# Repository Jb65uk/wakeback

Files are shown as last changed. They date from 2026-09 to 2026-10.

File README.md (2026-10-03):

# WakeBack

GPS WakeBack pucks for dinghy racing: log where you sailed, how fast and how heeled, then overlay everyone's tracks and replay the race on a projector or train against yourself.

```
wakeback/
├── viewer/index.html     the whole viewer, one file, works offline or served by the dock
├── app/                  Android phone/tablet app: the dock in your pocket, runs this same viewer (see app/README.md)
├── docs/PHONE_DOCK.md    how pucks upload to a phone hotspot instead of the dock (firmware notes)
├── server/app.py         dock server (Flask) — runs on the dock Pi, or your laptop for dev
├── tools/gen_fake_data.py    makes demo sessions in the exact puck CSV format
├── tools/fake_puck_upload.py pretends to be a puck landing on the dock
├── tools/fake_pucks.py       a dock full of pretend pucks checking in (for the Dock page)
├── data/sessions/<date>_<venue>/  one folder per session (sailing date + venue), one file per boat
├── data/venues.json      venues (Southport SC to start; new places are added as they're sailed)
├── docs/ROADMAP.md       where this is heading: your own sailing, friends, events
├── BUILD.md              build one puck on a breadboard: shopping list, wiring in stages, first track
├── hardware/carrier/     60 mm carrier PCB: Gerbers for JLCPCB, previews, assembly notes, generator
├── hardware/case/        3D-printed puck case: base, screw lid (O-ring), GPS shelf, deck cradle. STLs + generator
├── firmware/bench_test/  PlatformIO bench test: checks GPS, IMU, battery, Qi, records a test track
├── tools/pull_track.py   copies a recorded track off the puck over USB
└── firmware/             (next) the real puck firmware
```

## Quick start (VS Code)

1. Open this folder in VS Code. Install the recommended extensions when prompted.
2. `Terminal > Run Task > Install requirements` (or `pip install -r server/requirements.txt`).
3. Press F5 with **Run dock server** selected, then open http://localhost:5000.
4. The panel shows two demo sessions from the fake data: click **Sun 20 Sep, Southport SC** to load Sunday (three pucks plus Steve's phone, two races back to back in one log), press **Play**, then **B** for the big-screen projector view.
5. The course is already laid for the demo day (three marks, left to starboard). Under Races, WakeBack offers the likely races it found in the tracks: tick them and press **Add selected** (or press **Suggest races** to look again). Pick **Race 1**, then **Estimate** next to Wind. Tap **Tacks & gybes** under a boat, then filter to Tacks or Gybes, sort Worst first, and tap any one to jump the replay there.
6. `Run Task > Fake puck upload` to watch a session appear on the dock as a puck would post it.

No server? Just open `viewer/index.html` in a browser and drag files from `data/sessions/` onto it. Everything works except the sessions list and shared puck names.

## Dock page

Open **Dock** (tab at the top, or http://localhost:5000/dock). To see it with pucks in it on a laptop, run the **Fake pucks** task while the server's running: P1 full, P2/P3 charging, P4 comes back from sailing after ~20 s and uploads a session, P5 is on the pad but not charging, P6 has never checked in.

- Every puck: on the dock or away, battery % with charging / full / not charging, last upload (when, which day, how big, who sailed it), last seen, storage free, firmware (flags ones behind)
- Warnings up top: pucks not charging on the pad, low batteries
- Internet: online or not, and through what. "Connect to WiFi" scans for networks and joins one (club WiFi, a phone hotspot at an away venue). On the Pi this is real (NetworkManager, the default on Raspberry Pi OS); on a laptop it runs in demo mode with made-up networks so you can try it. The dock's own `wakeback` WiFi stays up regardless
- Dock health: disk space, clock, uptime, sessions stored, NAS backup (not set up yet)

Dock settings (environment variables):

| Variable | What | Default |
|---|---|---|
| `WAKEBACK_FLEET` | how many pucks the club has, so ones never seen still get a row | 0 |
| `WAKEBACK_WIFI` | the dock's own WiFi name, shown on the Dock page | wakeback |
| `WAKEBACK_OWNER` | owner of tracks from pucks with no owner set, e.g. `Southport SC` | none |
| `WAKEBACK_UPLINK_IF` | WiFi adapter used to reach the internet (USB dongle; onboard wlan0 runs the dock WiFi) | wlan1 |
| `WAKEBACK_PIN` | PIN needed to change the dock's WiFi | none |

## Phone / tablet app

`app/` is an Android app that runs the dock's API on the phone and shows this same viewer, so
everything above works on a phone or tablet, saved on the device, with no dock Pi:

- **No dock?** Turn on the phone's hotspot (`wakeback`): pucks join it and upload to the phone exactly as
  they would to the Pi — the dock is always the WiFi gateway on port 5000 (`docs/PHONE_DOCK.md`).
- **Sync** tab: copies each day's tracks, names, races and course both ways with this server
  (at home or on the Pi), using the API below — nothing extra on the server. **Invite a mate** sends the link.
- Build it on Windows with `app/setup.ps1` (see `app/README.md`).

The viewer knows when it's inside the app (`window.WakeBackApp`) and hands full screen and the GPX
download to the app; in a browser or on the Pi it behaves exactly as before.

## Viewer features

- Replay all boats on one clock, live speed/heel/pitch/VMG cards, 60 s trails, heading arrows
- Colour tracks by boat or by speed; satellite or OpenSeaMap chart base
- Races: split a day into time windows by hand (11:00–12:00, 12:00–13:30) or from the suggestions WakeBack works out from the tracks (boats milling about, then setting off together, then stopping; nothing is added until you tick it); stats, tacks, chart and replay all follow the selected race, and races are saved on the dock per day
- Wind direction typed in, estimated from the beating headings, or from **Get weather** (Open-Meteo: direction, speed and gusts for where and when you sailed, saved with the day, set per race, live on the map and big screen) → VMG, true wind angle, upwind/downwind averages, wind arrow on the map
- Tacks, gybes and mark roundings told apart, each with speed before/min, time back up to speed and metres lost; averages for each (tack loss, gybe loss, mark loss); click any one to jump the replay there
- Course marks: add them on the map, drag to adjust, set each to port (red) or starboard (green). Set per race, so a moved windward mark between races is fine. With marks placed, roundings are found at the real marks on any course shape (reaches included), and a rounding the wrong way is flagged
- Start and finish lines: tap the committee boat end then the pin end, drag to adjust; a line can be start, finish or both. With the gun time (typed, or estimated from the fleet) you get each boat's start: seconds late, distance back and speed at the gun, which end, and OCS (over early, and whether they went back). The finish gives order, elapsed time and gap to first. Saved per race with the marks
- Port tack red, starboard tack green: colour tracks "By tack", wind-angle chart and cards use the same colours, and the list shows which tack each manoeuvre ended on
- Wrong call? Change any tack/gybe/mark to something else, or "Not one"; corrections are saved with the session
- Align starts to race a mate from a different day or yourself from last week
- Big screen mode (B) for the projector: per-boat cards with your choice of data, loop replay, full screen (F)
- Puck numbers are fixed IDs (P3 is always P3, always the same colour); who sailed each puck is set per session, since pucks get handed out differently each time. Names you've used before pop up as suggestions
- Download all loaded tracks as one GPX to share

## Puck log format (what the firmware writes)

CSV, 10 Hz, one file per session, filename `puck<N>_<HHMMSS>.csv`:

```
t_ms,lat,lon,sog_kn,hdg,heel,pitch
1758364200000,53.6503120,-3.0101890,4.62,067,-11.3,-0.8
```

- `t_ms` UTC epoch milliseconds from the GPS
- `sog_kn` speed over ground in knots (GPS Doppler)
- `hdg` degrees true; fused IMU heading when available, otherwise course over ground
- `heel` degrees, positive to starboard
- `pitch` degrees, positive bow up

Phone/watch GPX files are accepted too; they just lack heel and pitch.

## Dock API

| Method | Path | What |
|---|---|---|
| GET | `/api/sessions` | list sessions: `[{"id":"2026-09-20_southport-sc","date","venue","venue_name","venue_new","files","count","races","owners":{"file":"name"}}]` (owners' emails are never listed) |
| GET | `/api/sessions/<session>/<file>` | fetch one track |
| POST | `/api/upload` | multipart `file` (+ optional `puck`, `owner_name`, `owner_email`, `sailor`); filed under the date of its first timestamp and the venue of its first position → `{session, file, venue, venue_name}` |
| GET / POST | `/api/venues` | list venues / add one `{"name","lat","lon","radius_m"}` (an `id` that already exists is returned as-is, for sync) |
| PUT | `/api/venues/<id>` | rename or move a venue, e.g. name an automatic "New venue near …" |
| POST | `/api/sessions/<session>/move` | `{"venue": id}`: a session filed at the wrong venue; merges into that venue's session for the day |
| DELETE | `/api/sessions/<session>/<file>` | remove a track |
| GET / PUT | `/api/sessions/<session>/races` | race windows for that day: `[{"name","start","end","gun","marks":[...],"lines":[{"kind":"start"/"finish"/"both","a":{lat,lon},"b":{lat,lon}}]}]`, times in epoch ms, a = committee boat end, b = pin |
| GET / PUT | `/api/sessions/<session>/meta` | whole-session marks, your corrections and the day's weather: `{"marks":[{"name","lat","lon","side":"port"/"stbd"}],"fixes":[...],"weather":{"src","lat","lon","got","pts":[[t_ms,dir,kn,gust],...]}}` |
| GET / PUT | `/api/sessions/<session>/crew` | who had which puck that day: `{"puck3": "Dave"}` |
| GET | `/api/sailors` | every name used in any session (for the name picker) |
| POST | `/api/pucks/checkin` | puck check-in every ~30 s on the pad: `{"puck":3,"battery_mv":4012,"charging":"charging"/"full"/"not","on_pad":true,"free_kb":12000,"total_kb":14336,"fw":"0.3.1","pending":1}`; reply carries dock time |
| GET | `/api/pucks` | every puck's status for the Dock page |
| GET | `/api/dock/status` | internet, disk, clock, uptime |
| GET / POST | `/api/wifi/scan`, `/api/wifi/connect` | find and join a WiFi network (on the Pi) |
| GET | `/api/hello` | dock time, used by pucks to confirm they're talking to the right box |

## On a NAS (or any Docker box): accounts, friends, admin

GitHub builds the server as a container on every change: `ghcr.io/jb65uk/wakeback-server:latest`.
Use `docker-compose.yml` from this repo (on a Ugreen NAS: Docker → Project → Create, paste it). It
listens on port 5090 and keeps everything in a `data` folder next to the compose file. Put it on the
internet with a Cloudflare tunnel public hostname pointing at `http://<nas-ip>:5090`. The compose file also
runs Watchtower, which checks GitHub every 30 minutes and swaps in a newer server image by itself, so the
NAS keeps up with the app without you touching it (put Cloudflare Access in front of `/admin` only, not the
whole site, or the app can't sign in), and a nightly backup container that writes `backups/wakeback-<date>.tar.gz`
(last 14 kept) — point the NAS's own backup or cloud sync at that folder so a copy leaves the building.
Password guessing is braked: 8 wrong tries on an email or 20 from one address in 10 minutes and that
login is refused for a while (a 429; the app says "Too many tries").

Set **`WAKEBACK_ADMIN`** to your email and accounts switch on:

- Everyone signs in (the app, or the viewer in a browser). New sign-ups wait for approval unless
  **Auto-approve** is on. The account with the admin email is the admin.
- **`/admin`** (admin only): approve/disable users, reset passwords, the auto-approve switch, every
  track (owner, sharing, remove), and a log of changes. Put Cloudflare Access on just this path if you like.
- Friends see each other's sails unless a sail is set **private**; tracks with no owner (a club
  dock's) are visible to all. The admin sees everything.
- Storage: `data/wakeback.db` (users, friends, tokens, log); who owns each track and its sharing
  live in the session's `owners.json`, so the phone app and a dock Pi keep the same files.

A dock Pi or the phone app runs without `WAKEBACK_ADMIN`: no logins, everything visible, as before.

## On the Pi

Same server. Set the Pi up as a WiFi access point (`wakeback`, no internet needed), run `app.py` under systemd, and point Chromium in kiosk mode at `http://localhost:5000` for the projector. Pucks join the AP when they sit on the charging pad and POST to `/api/upload`.

## Later list

Agreed, not built yet. Roughly in the order they'd make sense. The bigger direction (your own puck and phone, friends, events) is in `docs/ROADMAP.md`.

1. **Puck firmware** (ESP32-S3): 10 Hz GPS + IMU logging to the CSV format above, auto start/stop (see below), Dock check-in every ~30 s on the pad (and one as it's lifted off), upload to `/api/upload` when on the pad. The dock is found at the WiFi gateway, port 5000 — the Pi on its own WiFi, or a phone running the app on its hotspot (`docs/PHONE_DOCK.md`).
   - **Auto on/off:** asleep on the pad (never records there). Lifted → IMU wakes it → GPS fix. Records after >1.5 kn for 20 s; stops after ~10 min still, then sleeps.
   - **Travel-proof:** (a) over ~25 kn for a minute = not sailing, stop and discard; (b) needs boat-like heel/pitch rocking, not car motion; (c) only records near known venues (Southport + clubs added on the dock; dock asks "new venue?" first time somewhere new); (d) travel mode, set by triple-tap or from the dock page, sleeps until next put on a pad (use for long trips and flying).
   - Dock double-checks on upload and drops anything with road speeds or no boat motion.
   - GPS off while asleep, so a full charge lasts weeks in a bag.
2. **Home viewing, read-only**: dock syncs sessions to the home server (NAS/Tower) when online; published through a Cloudflare tunnel (e.g. puck.bridgesolutions.uk). Public copy runs the viewer locked: replay, races, colours, chart, focus a boat, tack list, big/full screen, download a track. No editing of names, races, marks or corrections; server refuses all changes. Choose per session whether it's published. Decide: club members only (Cloudflare Access email code) or anyone with the link.
3. **Up to 16 pucks**: 16 distinct colours (no red/green), compact one-row-per-boat projector view, stress test with a fake 16-boat race, bigger pad tray and power supply.
4. **Weather data**: ~~Open-Meteo~~ done — **Get weather** fills in wind direction, speed and gusts per race (hourly model). Next: the SSC weather station when it's running (log direction/speed every few seconds with a timestamp) for real shifts, lifts and headers — same `meta.weather.pts` format, just finer.
5. **Offline map backgrounds**: dock keeps the satellite/chart tiles for each venue it's been online at, so away venues work without internet.
6. **Leg analysis**: with marks placed, split each race into legs and show who gained or lost on each beat and run.
7. **NAS backup** of sessions from the dock.

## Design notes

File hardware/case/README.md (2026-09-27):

# WakeBack puck case

A round puck, 86 mm across and 37 mm tall, made to fit the carrier board and the parts on the shopping list. It has four printed parts (plus two optional ones for hanging it under a thwart, below):

| File | What it is | Print it |
|---|---|---|
| `out/wakeback-base.stl` | The cup. The battery, Qi coil, carrier board and TP4056 go inside. Bayonet lugs round the bottom | As it comes, floor down |
| `out/wakeback-lid.stl` | Screw-on lid with a thread and an O-ring seal | Top face down (the file is already that way up) |
| `out/wakeback-bridge.stl` | GPS shelf. Sits over the heel sensor on two legs | Flat side down (already that way up) |
| `out/wakeback-cradle.stl` | Deck mount. Drop the puck in and twist it clockwise to lock it | As it comes |

Plus two optional parts for hanging the puck **under a thwart** instead of on the deck:

| File | What it is | Print it |
|---|---|---|
| `out/wakeback-lid-mount.stl` | The same lid, with three bayonet lugs round its rim | Top face down (already that way up) |
| `out/wakeback-cradle-lid.stl` | A wider cradle that fits that lid. Screws to the underside of the thwart; the puck twists in upside down | As it comes |

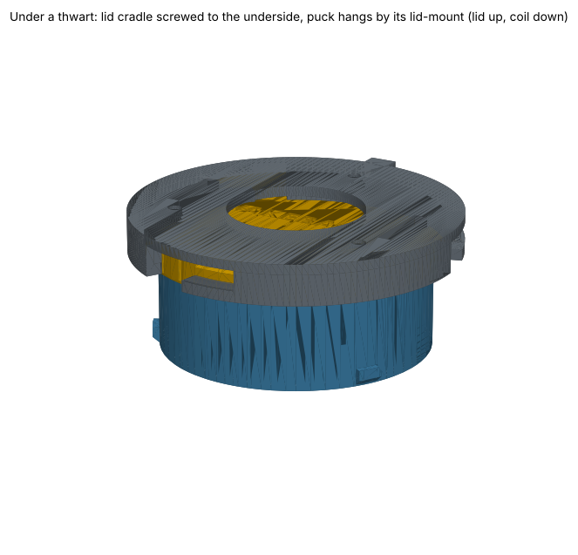
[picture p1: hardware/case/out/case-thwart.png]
under the thwart


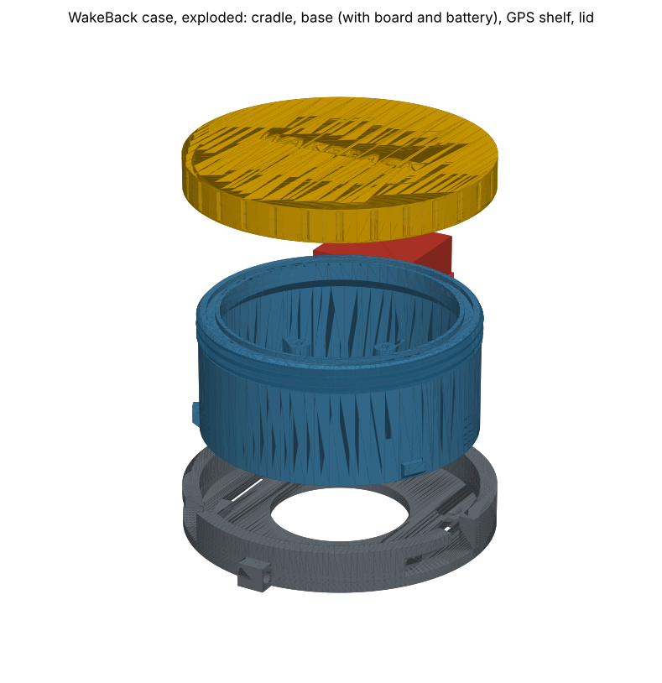
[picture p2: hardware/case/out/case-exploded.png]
exploded

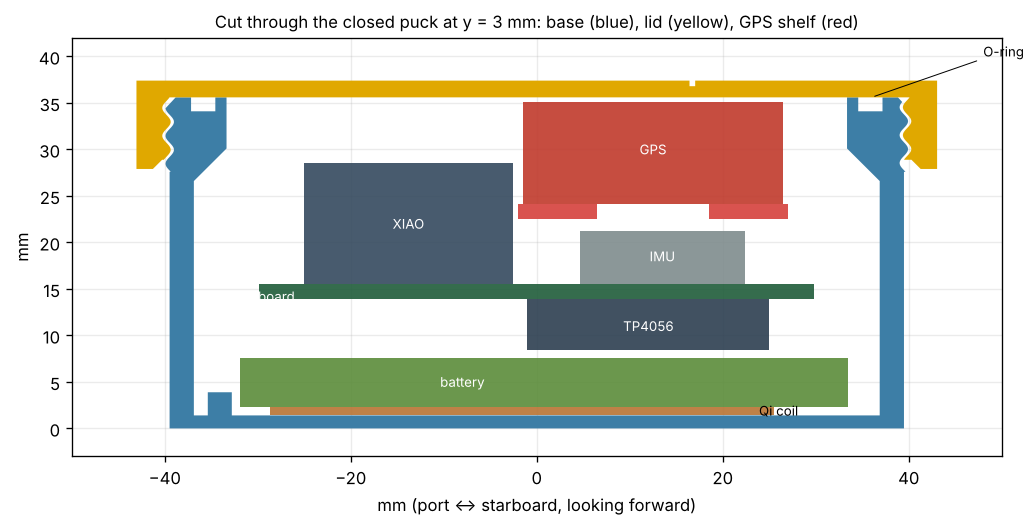
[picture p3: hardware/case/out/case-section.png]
section


## Print settings

- **PETG** (easy, tough) or **ASA** (better in sun for years). Not PLA: it softens in a hot boat and creeps.
- 0.2 mm layers, **5 perimeters**, 6 top and 6 bottom layers, 40 % gyroid infill. No supports needed.
- Flow at 100–103 %. Slight over-extrusion helps it stay watertight.
- Check the lid screws on before you print the cradle. If the thread is tight, raise `THREAD_CLR` in `gen_case.py` by 0.1 and re-run it.

## Also buy

- O-ring **70 × 2 mm**, nitrile. A pack of 10 is a couple of pounds.
- M2.5 stainless screws: **2 × 20 mm** (board and GPS shelf) and **1 × 8 mm** (third board hole). Self-tapping, or plain machine screws; either cuts its own thread in the plastic.
- A 1 mm self-adhesive foam pad for the top of the GPS, and double-sided foam tape.
- A little silicone grease for the O-ring.
- For the cradle: 3 × No.6 (3.5 mm) countersunk stainless screws, or a 20 mm Velcro strap through the two slots.

## Putting it together

1. **O-ring:** grease it lightly and press it into the groove on the rim of the base.
2. **Qi coil:** stick it to the middle of the floor, coil side down (touching the floor), shield sticker side up. The thinner the gap to the pad, the better it charges.
3. **Qi receiver board:** stick it down in the gap beside the battery, on the starboard-aft side (see `case-plans.png`).
4. **Battery:** it drops in between the four corner stops, sitting on the coil. It goes in at an angle so it misses the three board posts. Tilt it to get it past the rim.
5. **Carrier board:** onto the three posts, heel-sensor arrow toward the arrow on the outside of the base. One **M2.5 × 8** screw goes in the hole by the XIAO.
6. **GPS:** stick it on the shelf with foam tape, ceramic antenna facing up. Put the shelf over the heel sensor and fix it with the two **M2.5 × 20** screws, through the shelf legs and the board into the posts. Add the 1 mm foam pad on top of the GPS.
7. **Lid:** screw it on hand-tight. It's a normal thread: clockwise closes, anticlockwise opens.

The inside heights are tight. The battery top sits 6.3 mm under the board, and the TP4056 needs 5.5 mm, so keep the wires under the board flat.

## Check it's watertight

Before any electronics go in: put a dry tissue inside, screw the lid on, and hold it under water in a sink for 30 minutes (weigh it down). The tissue should come out dry. If it's damp, look for the leak: usually a thin wall or a gap between layers. Print again with 6 perimeters, or brush the outside with a thin coat of epoxy (XTC-3D or similar).

It floats. It displaces about 196 cm³ and weighs about 130 g with everything in.

## The cradle

- Screw or strap it to the boat with its **arrow pointing at the bow**.
- Hold the puck with its side arrow about 20° anticlockwise of the cradle arrow. Push it down, then twist it clockwise until the arrows line up. It clamps down as it goes home.
- Tie a thin lanyard through the eye on the cradle to the puck, in case of a big capsize.
- To charge it, twist it out and lay it on the Qi pad, flat side down.

## Under the thwart (lid-mount)

- Print the lid-mount and the lid cradle; the base, shelf and O-ring are the same. Swap lids as you like: both screw onto the same base.
- Screw (3 × No.6) or strap the lid cradle to the underside of the thwart, **arrow to the bow**. Screws go up into the wood; the heads sit inside the cradle.
- Screw the lid-mount onto the puck so the small arrow on its top face lines up with the base's bow arrow as near as you can (it doesn't need to be exact, see below).
- Offer the puck up lid-first, arrow about 20° anticlockwise of the cradle's arrow (as you look up at it), push, twist clockwise until the arrows meet. It hangs lid-up, charging coil down.
- Tie the lanyard through the cradle's eye. Upside down, the lugs are what's holding it; the lanyard is the belt to those braces.
- GPS: the antenna now faces up into the thwart. A wooden or GRP thwart is fine (plywood, a foam-cored GRP thwart, a Solo's mahogany one); a **carbon** thwart or a metal plate will block it — go on deck instead. Expect a slightly slower first fix and the odd extra metre of scatter.
- Heel and pitch: the puck is upside down and turned to whatever angle the lid tightened at. The firmware detects "upside down" from gravity at rest and learns the twist from the difference between its compass heading and the GPS course when you're sailing straight — nothing to set. Until that's in, the phone app's puck setup will have a "mounted: deck / under thwart" choice.
- The lid-mount also works on deck in the normal cradle (its lugs clear the deck cradle), so one puck can carry the lid-mount all the time and go either way.

## Things to know

- The status LED is inside. If you want to see it, print the lid in clear or natural PETG.
- **GPS power:** Beitian lists the BE-880 at 3.6–5.5 V, and the board feeds it 3.3 V. Most of these modules run happily on 3.3 V, and Stage 2 of the bench test will show you. If it won't get a fix or keeps dropping out, move the GPS red wire from the 3V3 pad to OUT+ on the TP4056 (battery voltage).
- Everything is generated by `gen_case.py`: sizes at the top, then the parts. Run it again after any change. It checks that nothing inside hits the case, that the lid unscrews cleanly, and that the puck drops into the cradle and twists to lock. Then it rewrites the STLs and pictures. It needs `pip install manifold3d trimesh numpy matplotlib`.

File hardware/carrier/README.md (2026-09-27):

# WakeBack carrier board v1

A 60 mm round, 2-layer board that replaces the breadboard. The same modules from the shopping list in `BUILD.md` solder onto it; there's nothing new to buy apart from the resistors and LED in 1206 size.

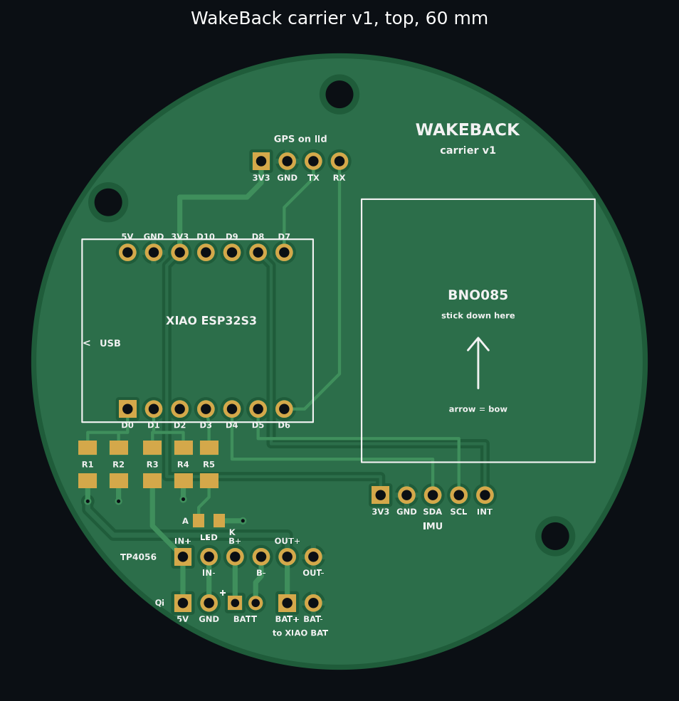
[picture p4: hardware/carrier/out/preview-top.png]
top


## Ordering from JLCPCB

1. Go to jlcpcb.com, **Order now**, upload `out/wakeback-carrier-v1-gerbers.zip`.
2. Settings: 2 layers, 1.6 mm, any colour, HASL lead-free finish. Leave everything else at default. It should read 60 × 60 mm.
3. "Remove order number": pick **Yes** or **Specify a location**, otherwise JLCPCB prints their number somewhere on the silkscreen.
4. Shipping: pick the economy option, not DHL.
5. Optional but recommended: turn on **PCB Assembly** (Economic, top side) and upload `out/wakeback-carrier-v1-BOM.csv` and `out/wakeback-carrier-v1-CPL.csv`. JLCPCB then fits R1–R5 and the LED (all their "basic" parts, about £8–10 extra). In the placement preview, check the LED's cathode mark sits on the K pad.

## What goes where

**Top side**
- **XIAO ESP32S3** on its header pins, USB-C facing the board edge (marked). Tip: use two 7-pin female headers so the XIAO can come off again.
- **R1 to R4: 100 kΩ, R5: 300 or 330 Ω**, all 1206. **LED** 0805: the A pad goes toward R5, and the green mark on the LED (cathode) toward K. (Skip if JLCPCB fitted them.)
- **BNO085**: stick it inside its outline with foam tape, arrow pointing to the bow. Five short wires from its pins to the IMU pads: 3V3 → VIN, GND, SDA, SCL, INT.
- **GPS pads**: four wires up to the BE-880 on the lid (3V3, GND, TX, RX, labelled from the GPS's point of view: its TX goes to the TX pad).

**Bottom side** (the pads are labelled on both sides)
- **TP4056** module inside its outline, USB end to the edge. Six short wires: IN+, IN−, B+, B−, OUT+, OUT−.
- **Qi receiver**: 5V and GND to the Qi pads. The board itself sits next to the battery, and the coil goes under the battery against the case base.
- **Battery**: JST-PH socket; the square pad is **+**. **Check the battery's polarity with a meter first.**
- **XIAO BAT pads**: two thin wires from the BAT+ and BAT− pads on the XIAO's underside to the BAT+/BAT− pads. Solder these to the XIAO *before* fitting it.

## Check it before powering up

With a meter on continuity, nothing connected yet:
- GND to 3V3: **not** connected
- OUT+ (VSYS) to GND: **not** connected
- IN− (Qi GND) to GND: **not** connected. They're deliberately separate, because the TP4056 protection circuit sits between them.

Then fit the modules one at a time in the same order as the breadboard stages in `BUILD.md`, running the bench test after each.

## Design notes

- Pins match `firmware/bench_test`: D0 battery sense, D1 pad sense, D3 LED, D4/D5 I2C, D6/D7 GPS, D8 IMU interrupt.
- Bottom layer is a ground fill. Clearances are 0.25 mm minimum (JLCPCB allows 0.127), copper is 0.5 mm from the edge, and labels are 0.8 mm tall or more.
- Three M2.5 mounting holes.
- The board is generated by `gen_carrier.py`. Change it and run it again: it checks clearances and that every connection is joined, then rewrites the Gerbers and the previews.

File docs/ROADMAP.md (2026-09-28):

# WakeBack roadmap: sailing's version of a running app

Everyone records their own sailing, looks back at it, and shares it with friends or an event.
The club base station (dock + projector) is one more way of recording, for training days with lots of people.

```
own puck ─► own phone (the app is a pocket dock) ─┐
                                                   ├─► WakeBack server (app.py, at home behind Cloudflare)
club pucks ─► dock Pi at the club ─────────────────┘        accounts · friends · events · venues
```

## Decisions (27 Sep 2026)

- **Accounts:** invite-only for now (you add people); can open up later without a rebuild.
- **Sign-in:** email + password (no email service needed); the admin resets passwords from /admin. The app stays signed in.
- **Privacy:** a new sail is visible to **friends** by default; any one can be made private or public.
- **Clean-up:** the QR phone-upload page is gone (mates use the app instead); old Bluetooth design dropped.

## Words

- **Session:** a sailing date + venue (`2026-09-20_southport-sc`). Everything replayed together.
- **Track:** one boat's log in a session. Has an **owner** (whose puck/phone sent it: can edit/delete it)
  and a **sailor** (who was in the boat; pucks get lent, so this is set per session).
- **Venue:** where you sailed. Found from the first position; somewhere new gets "New venue near …" until named.
- **Event** (stage 3): a set of tracks replayed together across owners: "Solo open, West Kirby", "Tuesday training".

## Stages

1. **Venues + owner/sailor** ✅ (this change)
   Sessions by date + venue; venue detection, naming, "wrong venue?" move; owner recorded on every track
   (phone profile, puck's owner, or the club); your old date-only folders are converted automatically;
   the app has a "You" profile; sync keeps venues and owners.
2. **Accounts and sharing** ✅
   Email + password accounts on the server (SQLite), approval or auto-approve, admin dashboard at /admin,
   friends, friends/private per track, only the owner (or admin) edits or deletes, the app signs in and
   keeps demo data separate. Not yet: a public read-only link, email "forgot password".
2b. **Sessions tab, stats and the league** ✅
   The app opens on a native Sessions list (tap to replay, Friends/Private switch per session), with Stats
   (miles, hours, sessions, average, top speed, fastest average, longest sail, favourite venue, miles by
   month, a fun comparison) and a friends' League (miles, hours, top speed, best average; this month / year /
   all time; medals). Numbers come from `server/stats.py` (`/api/stats`, `/api/league`, `stats` in
   `/api/sessions`, cached per session in `stats.json`) and the identical Dart port `app/lib/dock/stats.dart`
   for what's on the phone. Private sails stay off everyone's board, including the admin's.
3. **Events and "who else was there?"**
   Create an event, share a link/code, everyone adds their track; the server spots other WakeBack sailors at
   the same venue and time and offers to ask them; a feed of your and your friends' sailing.
4. **Puck setup from the app** (with the firmware) — TO DO, first once a puck is on the bench
   On first power-up (or holding the button) the puck puts up its own WiFi `wakeback-puck-N` for a couple of
   minutes; the app joins it and sends hotspot name + password, the owner, and a **puck key** (random,
   issued by the server, tied to the owner's account — club pucks to the club account). The puck sends the
   key with every upload; nobody types or remembers it. Lost/sold puck → revoke the key in /admin and set it
   up again. Lost hotspot password → change it on the phone and re-tell the puck the same way.
4b. **Firmware: calibrate itself, don't make the sailor do it** — TO DO (with the firmware)
   - Which way up: gravity at rest → deck cradle or hanging under the thwart; flip heel/pitch signs to suit.
   - Mounting twist: compass heading (BNO085) minus GPS course while sailing straight, averaged → the angle the
     puck is turned from the bow; re-learnt each time it's locked in, so the lid can stop at any angle.
   - Level: the "flat" heel/pitch offset from the first minutes at rest on the trolley/pontoon (and the cradle
     not being quite level on deck).
   - Magnetometer: run the BNO085's own calibration in the background; save it so it survives a power cycle.
   - GPS: nothing to calibrate, but do warm-start (save last fix + almanac) so it's ready when the boat hits the water.
   - Report all of it (orientation, twist, level, mag status) in the check-in so the app can show "puck 3 is
     under the thwart, calibrated" or warn when it isn't.
5. **Firmware from the dashboard → app → puck** — TO DO
   /admin: upload a `.bin` + version + notes; server serves `/api/firmware/latest`. The app shows
   "Puck 3 is on 1.2, 1.4 available — Update" on the Dock page and pushes it while the puck is on the pad /
   the hotspot (ESP32 OTA). Rule: keep the previous image and roll back if the new one doesn't check in
   within a minute — one bad build must not brick the club's pucks on a Saturday.
6. **App update button** ✅ (28 Sep)
   Every build is signed with the permanent key (GitHub secrets) and its build number is the run number, so
   the release tag `app-N` and the installed build match. The app checks the public releases feed (every 6 h,
   or Setup → About → Check), shows an "Update available" card with the release notes (the commit message)
   on Sessions and in Setup, downloads the APK and hands it to Android's installer (`app/lib/updates.dart`).
   One-off: phones with a throwaway-key build must uninstall once.
7. **2FA (TOTP) on accounts** — TO DO
   Authenticator-app codes, no SMS/email service; optional for sailors, on for the admin; admin can turn it
   off for someone who's lost their phone (from /admin, like a password reset).

8. **GDPR / keeping personal data tight** — TO DO
   The server holds names, emails, password hashes and GPS tracks (which are personal data too: where
   someone was, when). To do: a short privacy note in the app and on the server (what's kept, why, who sees
   it); emails never leave the server (already: the API only sends names) and never appear in the viewer,
   logs or the audit trail beyond what the admin needs; **delete my account** in the app and /admin that
   removes the account *and* their tracks (or hands club tracks to the club); **export my data** (a zip of
   your tracks + account details); a friend can only see your email if you've accepted them; keep the
   Cloudflare-fronted server HTTPS-only, back-ups encrypted, and the SQLite/data folder off any shared NAS
   share. No third-party analytics or trackers, so nothing to consent to beyond the account itself.

9. **Make it fun / useful — picked 27 Sep, in this order** ✅ (28 Sep; all five, phone side; server computes the same stats)
   1. **Personal bests**: when a session lands, a toast + card — "Fastest average this year", "Longest sail
      ever", "New top speed". Stats already has the numbers; keep a small `bests.json` per person.
   2. **Offline maps**: cache map tiles for your venues (a few zoom levels round each) so the tablet works
      with no signal at the club; "Download this venue" in Setup.
   3. **Share card**: a PNG of the track on the map + date/venue/miles/top speed/average, straight to WhatsApp
      via the Android share sheet.
   4. **Streaks & badges**: sailed N weekends running, 100 nm month, first 6 kn, dawn sail, most miles at a
      new venue, first capsize (heel > 80° for 10 s — the IMU knows). All from data already logged.
   5. **Wind vs speed**: upwind / downwind averages and bests, best 30-s VMG, most heel and capsizes (heel > 80°
      for 10 s), and a table by wind strength — from the day's weather (meta.weather, so pull it in on Replay)
      and the puck's heading and heel. `server/stats.py` and `app/lib/dock/stats.dart` compute it identically.
   Also: `app/lib/dock/badges.dart` (bests + 17 badges), `app/lib/dock/tiles.dart` (tile cache served at
   `/tiles/<layer>/z/x/y` by the phone's dock; the in-app viewer uses it), `app/lib/share_card.dart`.

Done 28 Sep, security: login/sign-up rate limits (accounts.py), Watchtower auto-updates the server image,
nightly backups to ./backups on the NAS (still to do: a copy off the NAS — the NAS's own backup app to the
PC or cloud). Still open: the update button needs the repo public (or a separate public releases repo).

Also still on you: add the GitHub signing secrets; scope Cloudflare Access to `/admin` only so the app can
create accounts.

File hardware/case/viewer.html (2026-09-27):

# WakeBack case

Round puck, 86 mm across and 37 mm tall. Screw-on lid with an O-ring, GPS on a shelf under the lid, twist-lock cradle for the deck. Drag to turn it, pinch or scroll to zoom.

Loading the model…

The small arrow on the side of the base points to the bow

TogetherApart

Cut in half Parts inside Lid Cradle

## Colours

## Print these

Part | Size, mm | Weight
Base | 80 × 82 × 36 | ~44 g
Lid, top face down | 86 × 86 × 10 | ~21 g
GPS shelf, flat side down | 30 × 49 × 9 | ~2 g
Cradle | 90 × 94 × 12 | ~30 g

Material

PETG or ASA

Layer

0.2 mm

Walls

5 perimeters

Top/bottom

6 layers

Infill

40 % gyroid

Supports

none

## Also buy

- O-ring 70 × 2 mm, nitrile
- 2 × M2.5 × 20 mm stainless screws (board and GPS shelf)
- 1 × M2.5 × 8 mm stainless screw (third board hole)
- 1 mm foam pad for the top of the GPS
- 3 × No.6 countersunk stainless screws for the cradle, or a strap
- A little silicone grease for the O-ring

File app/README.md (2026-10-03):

# WakeBack app (Android phone / tablet)

**The dock in your pocket.** The app runs the same API as `server/app.py` on the phone and shows the
**real viewer** (`viewer/index.html`) — races, marks, start/finish lines, tacks & gybes, wind, big screen,
crew names, venues, weather, the Dock page — all saved on the phone. Every session is a date + venue, and everything
your phone records is marked as yours (the You tab).

- **No dock Pi yet?** Turn on the phone's hotspot. Pucks join it and upload to the phone exactly as they
  would to the Pi (same `/api/pucks/checkin` and `/api/upload`).
- **Your server** (`app.py` at home or on the Pi): the **Sync** tab copies each day's tracks, names,
  races and course both ways. **Invite a mate** sends the server link.
- Works at the lake with no signal (Leaflet is bundled; only the map background needs internet).

```
app/
  lib/dock/store.dart         the dock's storage + rules, ported line for line from server/app.py
  lib/dock/pocket_dock.dart   the dock's HTTP API on port 5000 + serves the viewer pages
  lib/dock/stats.dart         miles / hours / speeds / wind / heel per track, totals and the league (= server/stats.py)
  lib/dock/badges.dart        personal bests ("new record") and badges, from your tracks
  lib/dock/tiles.dart         map tile cache: the dock serves /tiles/... so Replay works offline
  lib/share_card.dart         the picture of a session for WhatsApp
  lib/updates.dart            checks GitHub releases, downloads + installs a newer build
  lib/sync/server_sync.dart   two-way sync with your server (existing endpoints only)
  lib/demo/                   fake_pucks.py + gen_fake_data.py, ported
  lib/screens/                three tabs: Sails (list, Stats, League), Record, You. Replay (the viewer) opens when you tap a sail; Sync is behind the cloud on Sails
  assets/web/                 viewer pages (copied from ..\viewer by setup.ps1) + Leaflet
  test/dock_test.dart         checks the phone dock answers like app.py (incl. stats), and sync between two docks
  test/fixtures/              two small tracks whose numbers were taken from server/stats.py
```

## 1. Install Flutter (once, ~15 min)

1. Download the Flutter SDK zip for Windows (docs.flutter.dev → Get started → Windows → Android),
   extract to `C:\dev\flutter`, add `C:\dev\flutter\bin` to your user PATH, open a new terminal.
2. Install **Android Studio**, open it once to finish setup, then:
   ```
   flutter doctor --android-licenses
   flutter doctor
   ```
   Ticks for *Flutter* and *Android toolchain* are what matter.

## 2. Set up and test

```powershell
cd <wakeback folder>\app
.\setup.ps1
.\setup.ps1 -Test        # "All tests passed!"
```

## 3. Run it

- **Emulator on the PC:** Android Studio → Virtual Device Manager → + → Pixel 8 → newest image → ▶. Then `.\setup.ps1 -Run`.
- **Your phone (USB):** Developer options → USB debugging on, plug in, `.\setup.ps1 -Run`.
- **Mate's phone:** `.\setup.ps1 -Build` → send `WakeBack.apk`.

Press `r` in the terminal to reload after a change, `q` to quit.

## 4. Try it

1. **You → Advanced → Try the demo → Add a demo race morning.** Back on **Sails**, tap the day to replay it; in Replay open the panel (on a phone: the
   panel button) → today's date → it's the full viewer: suggested races, Race 1, Estimate wind, tacks & gybes,
   start results, **Big screen**, **Full screen**.
2. **You → Demo pucks** on, then **Advanced → See your pucks**: five pucks charging; P4 comes back after
   ~20 s and uploads a session that appears in the list.
3. **Sync:** run your server on the PC (`python server\app.py`), then in the emulator use
   `http://10.0.2.2:5000` (the emulator's name for your PC) → **Check** → **Sync**. Open
   `http://localhost:5000` on the PC: the demo day's there with its races and course.
   On a real phone use the PC's LAN address, e.g. `http://192.168.1.20:5000`.

## Pucks uploading to the phone (no dock)

1. Android Settings → Hotspot: name **wakeback** (or whatever you set in You → Advanced) and the password your
   pucks use. Turn it on.
2. Open WakeBack and keep it open (screen on is safest) while pucks sit on their charging pads.
3. Pucks join, check in every ~30 s and upload. Watch them on the viewer's **Dock** tab.

The firmware side is in `docs/PHONE_DOCK.md`: pucks look for the dock at their WiFi **gateway** on
port 5000, which is the Pi on its own WiFi and the phone on its hotspot — one code path for both.

## Troubleshooting

| Problem | Fix |
|---|---|
| `flutter` not recognised | PATH not set, or terminal opened before you set it |
| Build asks for a different NDK version | copy the `ndkVersion = "…"` line it prints into `android\app\build.gradle.kts` under `android {` |
| You → Advanced shows "Couldn't open port 5000" | another app has it; restart the phone. Replays still work, pucks can't upload until then |
| Sync: "Can't reach the server" | check the address (include `http://` or `https://`); from the emulator the PC is `10.0.2.2` |
| Map background blank | no internet for tiles — tracks, marks and lines still draw |

Anything else — paste the error.

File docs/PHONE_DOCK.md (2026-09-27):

# Phone as the dock — what the puck firmware needs

No new protocol. A phone running the WakeBack app answers every dock URL the same way
`server/app.py` does, on port **5000**. So the firmware has one upload path, and only
needs to know *where* the dock is:

**The dock is the WiFi gateway, port 5000.**

| Where | Puck joins | Gateway = | Dock URL |
|---|---|---|---|
| Club, dock Pi | the Pi's own AP `wakeback` | the Pi | `http://<gateway>:5000` |
| No dock | the phone's hotspot `wakeback` | the phone | `http://<gateway>:5000` |

Firmware flow when on the pad (unchanged, just the address lookup):

1. Join SSID `wakeback` (password in NVS).
2. `GET http://<gateway>:5000/api/hello` → `{"dock":"wakeback","time_ms":…}` confirms it's a dock
   (and sets the clock if there's no GPS time yet). No reply → try again later.
3. `POST /api/pucks/checkin` every ~30 s (and once as it's lifted off the pad).
4. `POST /api/upload` (multipart `file`, plus `puck=puckN`) for each finished session;
   delete from flash only after a `200` with `{"ok":true}`.

On the ESP32: `WiFi.gatewayIP()` after connecting.

Things that differ with a phone, and the app handles:

- The phone only accepts uploads while WakeBack is open (Android may pause it in the
  background). Pucks just retry on their next check-in.
- `/api/dock/status` reports `can_manage_wifi: false` and `phone: true`; the Dock page hides
  "Connect to WiFi" and says to use the phone's hotspot.
- Android hotspots often use `192.168.43.1` or `10.x.x.1`, never assume the address — use the gateway.

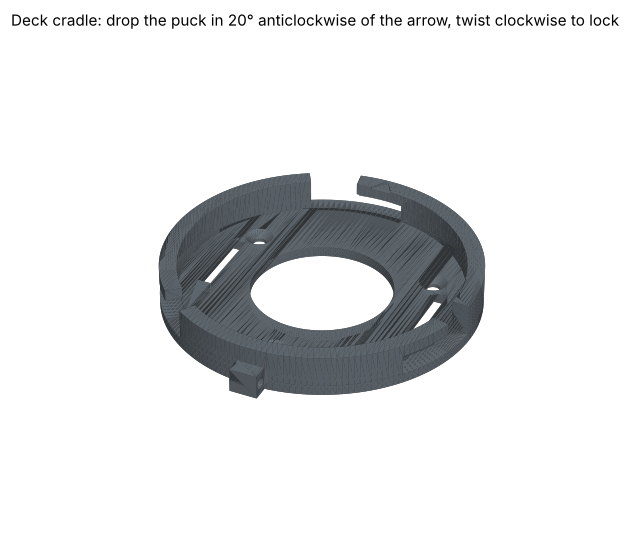
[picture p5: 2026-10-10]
hardware/case/out/case-cradle.png

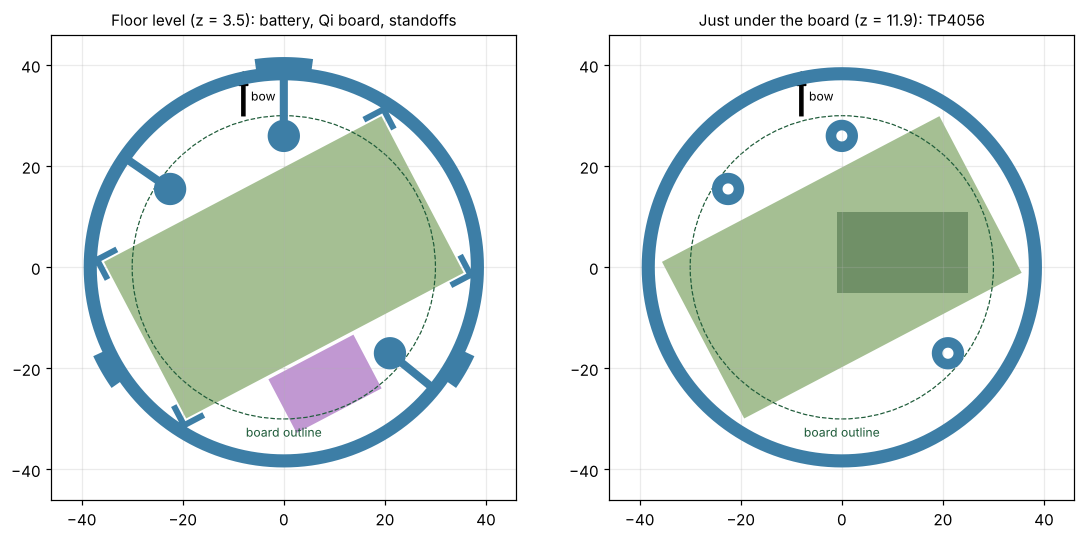
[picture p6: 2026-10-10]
hardware/case/out/case-plans.png

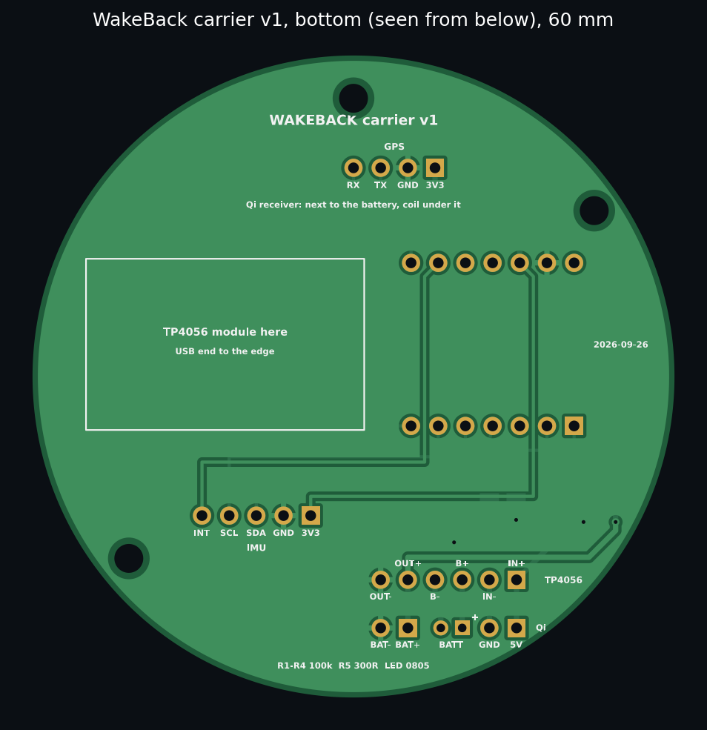
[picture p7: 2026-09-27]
hardware/carrier/out/preview-bottom.png

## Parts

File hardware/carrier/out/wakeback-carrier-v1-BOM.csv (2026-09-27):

Comment | Designator | Footprint | JLCPCB Part #
100k | R1,R2,R3,R4 | R_1206 | C17900
300R | R5 | R_1206 | C17887
LED red | D1 | LED_0805 | C84256

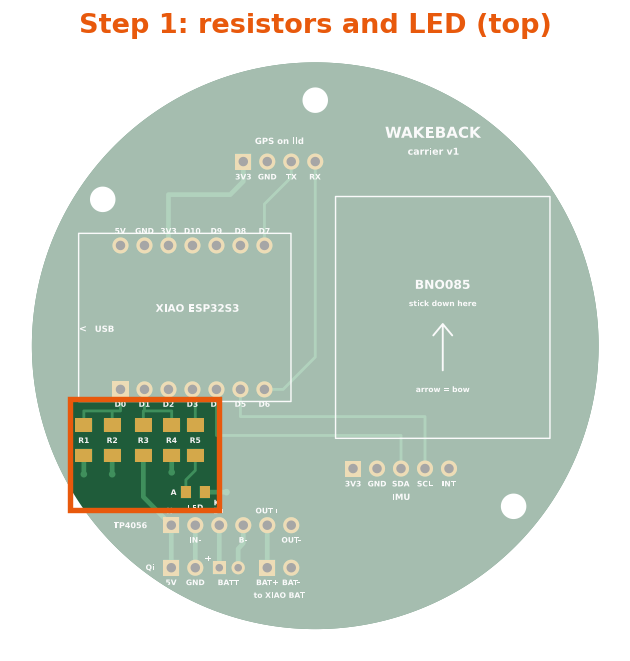
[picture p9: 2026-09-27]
hardware/carrier/out/step-parts.png

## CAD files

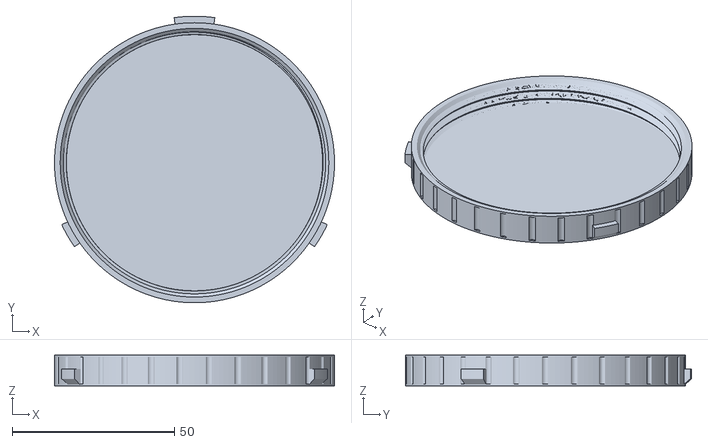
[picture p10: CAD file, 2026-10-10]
hardware/case/out/wakeback-lid-mount.stl
86.3 x 88.3 x 9.50

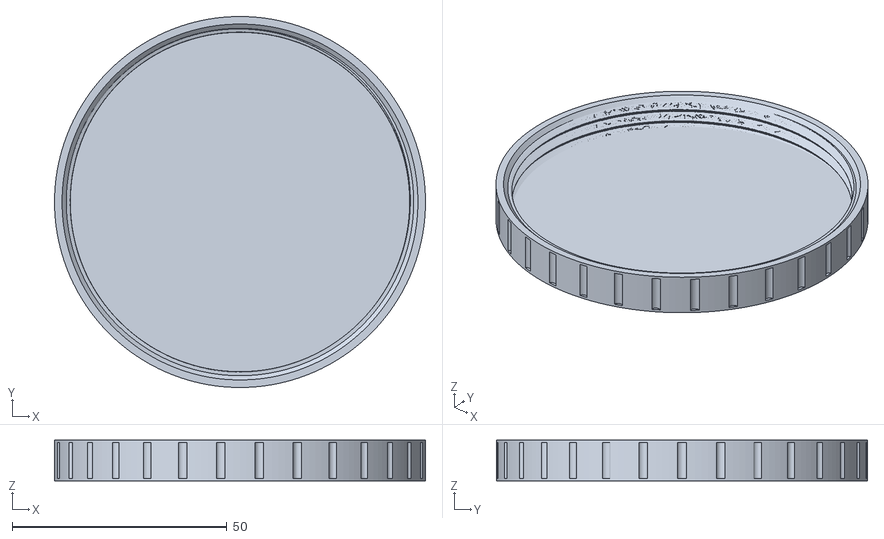
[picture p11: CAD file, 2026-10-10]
hardware/case/out/wakeback-lid.stl
86.3 x 86.3 x 9.50

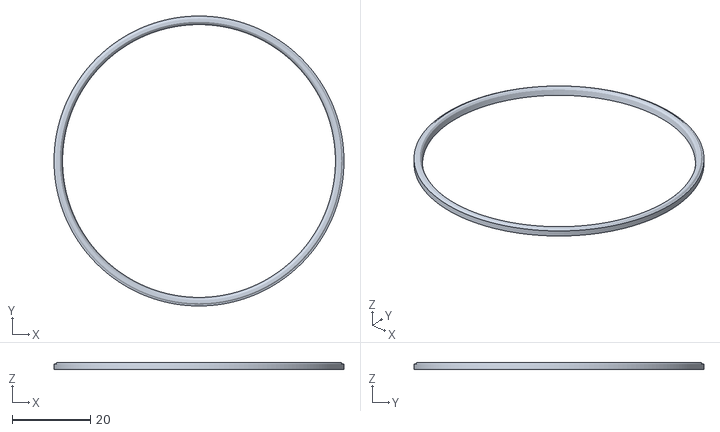
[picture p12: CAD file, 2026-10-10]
hardware/case/out/wakeback-gasket-tpu.stl
74.2 x 74.2 x 1.90

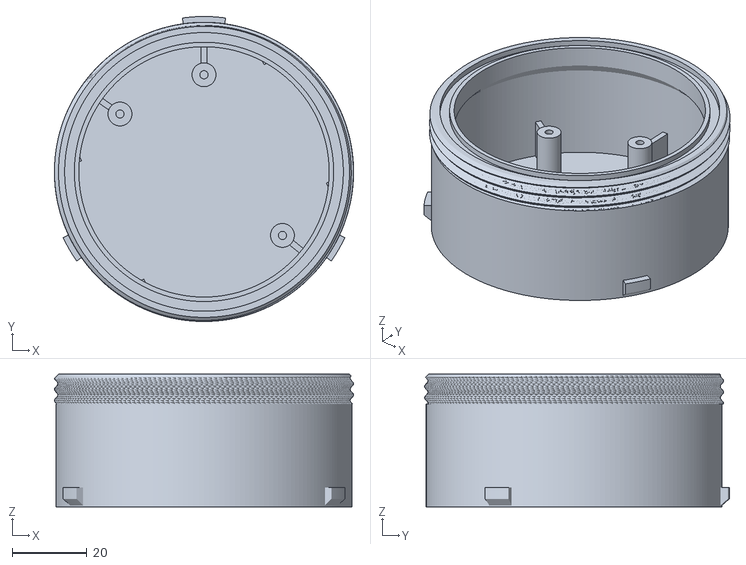
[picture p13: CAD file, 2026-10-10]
hardware/case/out/wakeback-base.stl
80.1 x 81.6 x 35.6

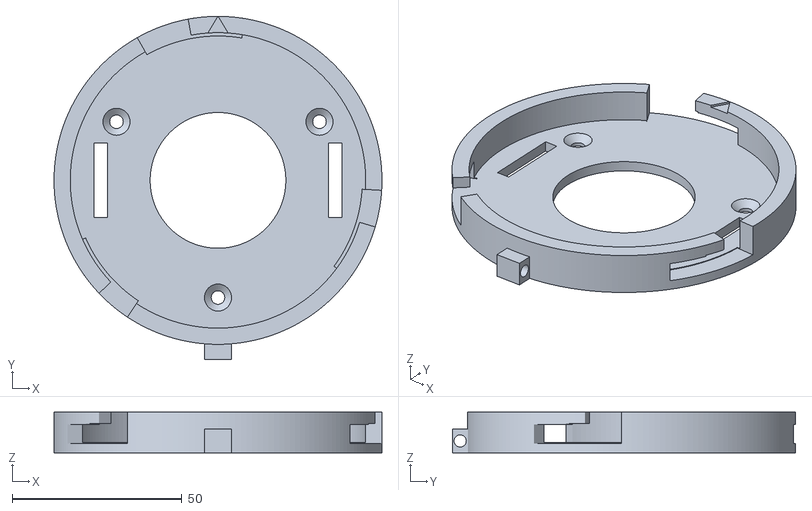
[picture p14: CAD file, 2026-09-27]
hardware/case/out/wakeback-cradle-lid.stl
96.7 x 101.2 x 12.0

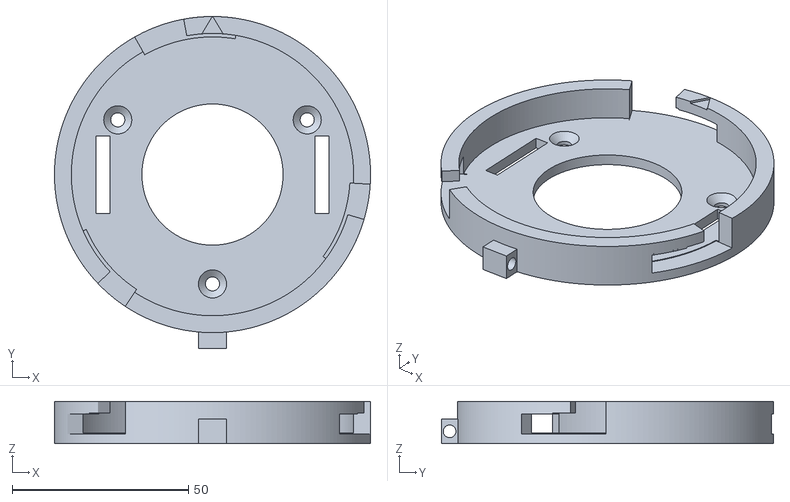
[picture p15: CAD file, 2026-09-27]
hardware/case/out/wakeback-cradle.stl
89.6 x 94.1 x 12.0

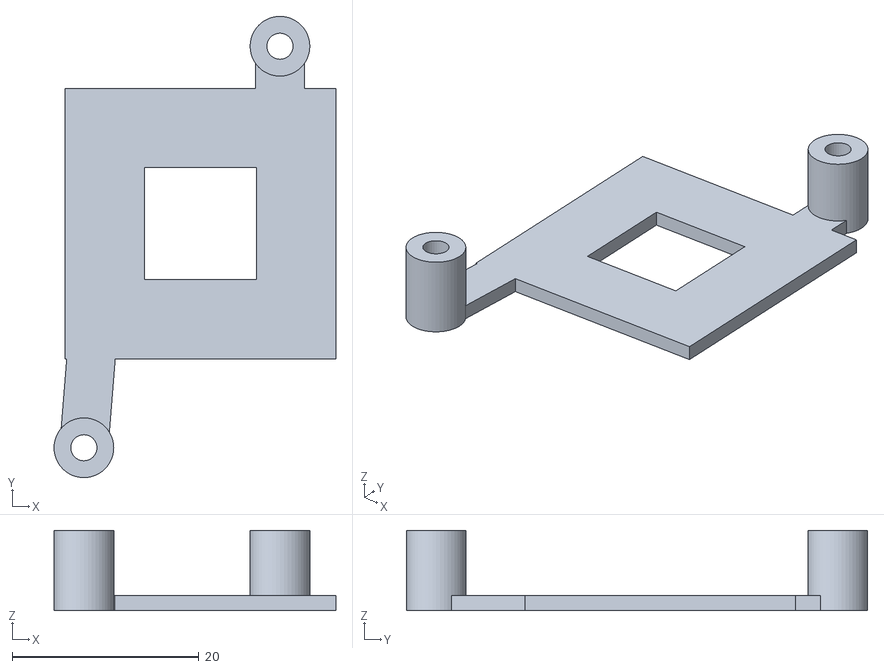
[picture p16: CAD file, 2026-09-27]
hardware/case/out/wakeback-bridge.stl
30.2 x 49.4 x 8.60

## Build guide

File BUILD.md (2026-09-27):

# Build one puck on a breadboard

Goal: one working puck on the bench, then a first real track off the water, before any PCB or case.
Build it in stages and check each one before adding the next. If something doesn't work, you'll know which part it is.

**Two ways to build it:** on a breadboard (below), or on the **carrier board**: a 60 mm round PCB the same modules solder onto, about £5 for five from JLCPCB. See `hardware/carrier/README.md`. The stages and checks below are the same either way.

## Shopping list

Prices checked 26 Sept 2026, including VAT. Stock moves, so check before ordering.

| Part | Where | Price | Notes |
|---|---|---|---|
| Seeed XIAO ESP32S3, **pre-soldered headers** | [The Pi Hut](https://thepihut.com/products/seeed-studio-xiao-esp32s3) | £8.20 | For the breadboard. The PCB later uses the Plus (16 MB); this one has 8 MB, plenty for testing |
| Adafruit BNO085 9-DOF IMU (heel/pitch) | [SB Components](https://shop.sb-components.co.uk/products/adafruit-9-dof-orientation-imu-fusion-breakout-bno085-bno080-stemma-qt-qwiic) (in stock) or [The Pi Hut](https://thepihut.com/products/adafruit-9-dof-orientation-imu-fusion-breakout-bno085-bno080-stemma-qt-qwiic) (sold out today) | £27 | Comes with header pins to solder on |
| Beitian **BE-880** GPS (u-blox M10) | Amazon UK / AliExpress, search "BE-880 GPS M10" | about £15–20 | Make sure it says **BE-880** or M10. The older **BN-880** (M8) works but isn't as good. Ignore its compass wires |
| LiPo 1200 mAh, JST-PH, with protection | [The Pi Hut](https://thepihut.com/products/1200mah-3-7v-lipo-battery) | £8 | 62 × 35 × 5 mm. Any 1000–1200 mAh single-cell with protection will do |
| TP4056 charger boards **with protection** (DW01), USB-C, pack of 5+ | Amazon UK, search "TP4056 USB-C protection" | about £6 | The ones with 6 pads: IN+ IN− B+ B− OUT+ OUT− |
| Qi receiver, 5 V 1 A, with coil | [Amazon UK (VBESTLIFE)](https://www.amazon.co.uk/Vbestlife-Wireless-Charging-Receiver-Standard-default/dp/B08H8LL341) | about £5–8 | Any "Qi receiver module 5V 1A" |
| Qi charging pad | any phone pad | about £10 | Or one you already have |
| Breadboard, jumper wires, 4 × 100 kΩ, 1 × 330 Ω, 1 LED | any starter kit | about £10 | Skip what you already have |
| JST-PH 2-pin sockets / pigtails | Amazon UK | about £5 | So the battery plugs in rather than being soldered |

For the **carrier board** instead of a breadboard, add: a JST-PH 2-pin through-hole socket (B2B-PH-K-S), and two 7-pin 2.54 mm female headers for the XIAO. The resistors and LED can be fitted by JLCPCB when you order (about £8–10 extra); to solder them yourself, add 100 kΩ ×4 and 300–330 Ω ×1 in **1206** size and an **0805** LED.

About **£85–95** with the pad and breadboard, **about £70** for the puck parts alone.

Tools: soldering iron (IMU headers, two wires on the XIAO's battery pads, TP4056 wires), multimeter (to check battery polarity).

### Before you start: LiPo safety
- **Check the battery polarity with a multimeter before plugging it in anywhere.** Cheap LiPos swap red and black on the JST plug more often than you'd think. Reversed = dead charger, possibly a hot battery.
- Never short the battery leads, and never leave a LiPo charging unattended on a bench.
- For now, don't leave it on the Qi pad **and** plugged into USB at the same time (two chargers on one cell). A minute for testing is fine.
- The TP4056 boards charge at 1 A out of the box. That's quicker than this battery likes (it recommends about 0.6 A). For bench tests it's OK; before real use, swap the small resistor marked R3 (or R-prog) for **2.2 kΩ** (about 550 mA).

## Software

1. Install the **PlatformIO** extension in VS Code.
2. Open the folder `firmware/bench_test` (just that folder) in VS Code.
3. Plug the XIAO in with a USB-C data cable. Click **Upload** (→ on the blue bar). First time takes a few minutes while it downloads the tools.
4. Click the **Serial Monitor** (plug icon). Type `h` and Enter for the commands.

Every second it prints a status line like:

```
GPS 3D fix, 14 sats, 10 Hz, +/-1.8 m | 3.21 kn 045 deg | heel +12.3 pitch  -1.0 | batt 3.98 V 78% | off the pad
```

## Stage 1: the XIAO on its own

Push the XIAO into the breadboard across the middle gap, USB end at the edge. Upload the bench test.

**Check:** the monitor says `GPS: NOT FOUND` and `IMU: NOT FOUND` (nothing's connected yet) and the LED blinks slowly. Storage says ok with about 6 MB free.

## Stage 2: GPS

| BE-880 wire | goes to XIAO |
|---|---|
| VCC (red) | 3V3 |
| GND (black) | GND |
| TX (from the GPS) | **D7** |
| RX (to the GPS) | **D6** |
| SDA / SCL (compass) | leave unconnected |

Wire colours vary between sellers: go by the labels on the board. TX goes to the XIAO's receive pin (D7), and RX to D6. Crossed is correct.

Press the XIAO's reset button (or re-open the monitor). Put the GPS on a window sill or outside, antenna (the square ceramic side) facing the sky.

**Check:** `GPS: found at 38400 baud, set to 10 Hz`. Within a minute or two outside: `3D fix`, 10+ sats, `10 Hz`, accuracy under 3 m. Indoors it may never get a fix; that's normal.

If it says NOT FOUND: swap D6/D7, check 3V3 and GND.

## Stage 3: heel and pitch (BNO085)

Solder the header pins onto the BNO085 first.

| BNO085 pin | goes to XIAO |
|---|---|
| VIN | 3V3 |
| GND | GND |
| SDA | **D4** |
| SCL | **D5** |

Reset. **Check:** `IMU: found`. Put the breadboard flat and type `z` (zero). Heel and pitch read about 0.

Now decide which way the puck will sit on the boat, and tip the board the way the boat heels **to starboard**: heel should go **positive**.
- If tipping sideways changes *pitch* instead: type `a` (swap axes), sit it level, `z` again.
- If heel goes negative: type `f` (flip).

These settings are remembered.

## Stage 4: status LED

D3 → 330 Ω → LED long leg; LED short leg → GND.

**Check:** slow blink with no GPS fix, one blink a second with a fix, double blink when recording.

## Stage 5: battery and charger

**Unplug the USB first.**

1. **Check the battery polarity** with the multimeter.
2. Battery → TP4056 **B+ / B−**.
3. TP4056 **OUT+ / OUT−** → the XIAO's **BAT+ / BAT−** pads underneath (solder two short wires). Nothing goes to the XIAO's 5V pin.
4. Battery sense: TP4056 OUT+ → 100 kΩ → **A0** (D0) → 100 kΩ → GND.

Unplug USB: the XIAO should run from the battery (LED blinking). Plug USB back in to see the monitor.

**Check:** `batt 3.9x V nn%`. The reading should be within about 0.05 V of the multimeter across the battery.

## Stage 6: wireless charging

1. Qi receiver 5 V out → TP4056 **IN+ / IN−** (the pads beside its USB socket).
2. Pad sense: Qi 5 V → 100 kΩ → **A1** (D1) → 100 kΩ → GND.
3. Lay the Qi coil flat on the pad.

**Check:** the TP4056 red LED lights (charging), the monitor says `on the pad, charging`. Lift the coil: `off the pad`. When full the TP4056 LED goes blue/green and the monitor says `full`.

If the pad doesn't start: centre the coil, and try another pad. Some are fussy with small coils.

## Stage 7: first real track

1. In the monitor type `p1` (this is puck 1), then `r` to start recording.
2. Unplug USB, put the breadboard in a food box, and go for a walk, a bike ride, or better, a sail. It records whenever it has a fix.
3. Back home: plug in, **close the serial monitor**, then in a terminal in the project folder:

```
pip install pyserial
python tools/pull_track.py
```

It saves `puck1_HHMMSS.csv`. Drop it on the viewer (or add `--upload` with the dock server running and it lands in the right session).

About 3 hours fits on the 8 MB XIAO (about 1.9 MB an hour as text). The real firmware stores it more compactly.

## What's not on the breadboard (yet)

- The AO3401 GPS power switch (only matters for sleeping for weeks).
- Wake-on-movement, auto start/stop, dock check-ins and uploads. That's the real firmware, next.

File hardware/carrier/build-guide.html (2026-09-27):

# WakeBack build guide

Building the first puck on the carrier board, from ordering the PCB to a real track on the viewer. No electronics knowledge needed beyond being able to solder. Do the steps in order: each one ends with a test, so if something's wrong you know exactly which bit.

This is the first build. The board and the test firmware have been checked on the computer but not yet built for real. Treat puck one as the prototype, and expect to find a thing or two to change.

## What you're building

One round board with everything wired to it. The small computer (XIAO) and the heel sensor sit on top. The charger module sits underneath, the battery below that, and the wireless charging coil under the battery. The GPS goes in the lid, facing the sky, on four wires.

{{STACK}}

Top of the carrier board: XIAO outline on the left, heel sensor outline on the right, pads labelled for GPS, IMU, charger, Qi and battery

The board, top side. 60 mm across.

Bottom of the carrier board, seen from underneath: outline where the charger module sits and the same pads labelled

Underneath, as you'll see it when you turn it over.

### How it's all connected

{{OVERVIEW}}

powergrounddatacharging

## Order the boards

Done

Shipping: DHL is about £30. Pick the cheapest economy option at checkout instead (usually called Global Standard Direct Line or similar): a few pounds, and about 2 weeks.

Yes, you just send it. The file wakeback-carrier-v1-gerbers.zip is everything a PCB factory needs. Don't unzip it: upload the zip as it is.

1. Go to jlcpcb.com and make an account.
2. Click Order now, then Add gerber file, and pick the zip.
3. After a few seconds it shows a picture of the board and fills in the size: it should say 60 × 60 mm and 2 layers. Click the preview to check it looks like the pictures above.
4. Check the settings below. Most are already right.
5. Save to cart, then Checkout. Pick a shipping option: the cheapest takes a couple of weeks, DHL/FedEx about a week.

Setting | Choose | Why
Base material | FR-4 | standard
Layers | 2 | filled in from the files
PCB qty | 5 | the minimum, and the same price as fewer
PCB thickness | 1.6 mm | standard
PCB colour | Green | cheapest and quickest; any colour works
Surface finish | HASL (with lead) or LeadFree HASL | either is fine to hand-solder
Outer copper weight | 1 oz | standard
Remove order number | Yes (small extra charge) | otherwise they print a code somewhere on the board. Harmless, so No is fine too
PCB Assembly | On (recommended) | JLCPCB fits the five resistors and the LED for you. See below
SMT stencil | Not needed

### Let JLCPCB fit the resistors and LED (recommended)

The tiny parts are the fiddliest bit to hand-solder, and they're all JLCPCB "basic" parts, so it's cheap to have them fitted. Everything else (XIAO, modules, battery socket, wires) you still solder yourself.

1. On the same order page, switch PCB Assembly on. Choose Economic, Top Side, PCBA Qty 2 (the other 3 boards come bare). Tooling holes: Added by JLCPCB. Click Confirm.
2. Upload wakeback-carrier-v1-BOM.csv as the BOM and wakeback-carrier-v1-CPL.csv as the CPL (pick-and-place) file, then Process BOM & CPL.
3. It should find three parts, all ticked: C17900 (100 kΩ ×4), C17887 (300 Ω) and C84256 (red LED). If one says out of stock, pick any other 1206 resistor of the same value, or any 0805 LED, from the basic list.
4. On the placement preview, zoom in on the LED. Its cathode mark (the little line or dot) should sit on the pad labelled K, toward the right. If it's the wrong way round, select it and rotate it 180°. Resistors don't matter.
5. Carry on to the cart. Expect roughly £8–10 extra for assembly (a setup fee plus pennies for the parts).

Expect about £5 for the boards plus shipping. UK VAT is normally added at checkout on small orders, so there's nothing extra to pay on delivery. It'll ask you to confirm the order after their engineers check the files, usually within a few hours.

## Parts and tools

Got everything

Part | How many | Notes
Carrier board (from JLCPCB) | 1 (of 5)
Seeed XIAO ESP32S3, pre-soldered headers | 1 | The Pi Hut (https://thepihut.com/products/seeed-studio-xiao-esp32s3), £8.20
Beitian BE-880 GPS (u-blox M10) | 1 | Amazon / AliExpress, about £15–20. Must say BE-880 or M10
Adafruit BNO085 heel sensor | 1 | SB Components (https://shop.sb-components.co.uk/products/adafruit-9-dof-orientation-imu-fusion-breakout-bno085-bno080-stemma-qt-qwiic), £27
TP4056 USB-C charger with protection (6 pads) | 1 | Amazon pack of 5, about £6
Qi receiver 5 V 1 A, with coil | 1 | Amazon (https://www.amazon.co.uk/Vbestlife-Wireless-Charging-Receiver-Standard-default/dp/B08H8LL341), about £5–8
LiPo 1200 mAh, JST-PH plug, protected | 1 | The Pi Hut (https://thepihut.com/products/1200mah-3-7v-lipo-battery), £8
The next three are only needed if you didn't have JLCPCB fit them:
Resistor 100 kΩ, 1206 size | 4 | R1 to R4. Marked "104" on the part
Resistor 300 or 330 Ω, 1206 size | 1 | R5. Marked "301" or "331"
LED, 0805 size, any colour | 1
JST-PH 2-pin socket, through-hole (B2B-PH-K-S) | 1 | for the battery to plug into
Female header, 1 × 7, 2.54 mm | 2 | so the XIAO can come off again
Thin silicone wire, 26–28 AWG, several colours | 1 m | red, black, and two or three others
Qi charging pad | 1 | any phone pad

### Tools

- Soldering iron with a fine tip (330–350 °C), solder, and a flux pen
- Fine tweezers, for the tiny resistors
- Multimeter: for checking the battery's + and −, and for the continuity checks
- Foam double-sided tape, and a USB-C data cable

## Soldering tips

### The tiny parts (resistors and LED)

They look fiddly but they're the easiest thing on the board once you know the trick:

1. Put a small blob of solder on one of the two pads.
2. Hold the part with tweezers, heat that blob, and slide the part into it. Take the iron away and it's held.
3. Solder the other end normally.
4. Go back and touch the first end again with a dab of fresh solder so it flows properly.

### Wires

- Strip about 2 mm, twist, and tin the end (coat it with solder) before it goes near the board.
- Push the wire through the pad's hole from the side the module is on, and solder on the other side. Snip the spare.
- Keep wires short and neat: just long enough to reach, plus a little slack.

LiPo battery safety. Before you plug the battery into anything, check its + and − with the multimeter. Cheap batteries often have the red and black swapped in the plug, and a backwards battery can destroy the charger or make the battery swell. Never short the leads, and never leave it charging unattended on the bench.

## Set up the computer

Done

You'll use this to put the test program on the XIAO and to see what it reports.

1. Install VS Code from code.visualstudio.com.
2. In VS Code, click the Extensions icon on the left (four squares), search PlatformIO IDE, and install it. It takes a few minutes and may ask to restart.
3. Unzip wakeback.zip somewhere, then File → Open Folder… and pick wakeback/firmware/bench_test (that folder, not the whole project).
4. Wait until the blue bar at the bottom shows a ✓ tick and a → arrow. That means it's ready.

You'll use three buttons on that blue bar:

- ✓ Build makes sure the program compiles.
- → Upload puts it on the XIAO.
- Plug icon: Serial Monitor shows what the XIAO is saying. Type commands at the bottom and press Enter.

Check: click ✓ Build now, before any hardware arrives. The first time it downloads its tools (several minutes). It should end with SUCCESS. If it shows an error instead, send it to me: the test program hasn't been built on a real machine yet, and a small fix may be needed.

1

## Resistors and LED

Done

Had JLCPCB fit these? Just check the LED is there and the right way round, tick Done and skip to Step 2.

Soldering them yourself? You need: the board, 4 × 100 kΩ, 1 × 300 or 330 Ω, a 0805 LED.

Board with the five resistor positions and LED position highlighted, bottom left of the XIAO outline

Label on board | Part | Marked
R1 R2 R3 R4 | 100 kΩ | 104
R5 | 300 or 330 Ω | 301 or 331
LED | LED, see below

Resistors can go either way round. The LED can't.

{{LED}}

Check: each part sits flat with both ends shiny and joined. Nothing bridges across to its neighbour.

2

## XIAO

Done

You need: the XIAO, two 7-pin female headers, a short red and a short black wire (about 60 mm each).

Board with the XIAO position highlighted; the USB end is marked at the left edge

1. First, the battery wires. Turn the XIAO over. Near one end there are two small pads labelled BAT+ and BAT− (look for the + and −). Solder the red wire to BAT+ and the black to BAT−. Do this now, because once the XIAO is fitted you can't reach them.
2. Push the two female headers into the board's 14 XIAO holes from the top. Solder one pin of each underneath, check they're straight, then do the rest.
3. Plug the XIAO into the headers with its USB socket at the board edge, matching the "USB <" marking.
4. Leave the two battery wires loose for now. They go on in step 6.

Orientation matters. If the XIAO goes in the wrong way round, nothing will work and the power pins will be in the wrong place. The USB socket must point at the board edge.

3

## First power-up

Done

1. Plug the XIAO into the computer with the USB-C cable.
2. In VS Code click → Upload. Wait for SUCCESS.
3. Click the plug icon to open the Serial Monitor. Press the XIAO's tiny R (reset) button to see it start.

WakeBack bench test starting…
GPS:     NOT FOUND. Check VCC/GND, and that GPS TX goes to D7 and GPS RX to D6.
IMU:     NOT FOUND. Check VIN/GND, SDA to D4, SCL to D5.
Storage: ok, 5.9 MB free

Check: you see something like the above. GPS and IMU not found is right: they aren't fitted yet. The LED on the board blinks slowly.

Upload fails? Unplug the USB, hold the XIAO's B (boot) button, plug back in, let go, and upload again. You only need to do this the first time.

4

## GPS

Done

You need: the BE-880 GPS and its wires. It'll live in the lid, so give the wires enough length to reach (about 80 mm) and cut the rest off.

Board with the four GPS pads highlighted at the top: 3V3, GND, TX, RX

Only four of its six wires are used. Go by the labels printed on the GPS board, not the wire colours: they vary between sellers.

The pads are named from the GPS's side: the GPS's TX wire goes to the pad marked TX.

{{GPS}}

1. Press the XIAO's R button with the monitor open.
2. Take the board near a window or outside, with the GPS's flat ceramic square facing the sky.

Check: it says GPS: found at 38400 baud, set to 10 Hz, sea mode. Within a couple of minutes outside, the status line shows 3D fix, 10 or more sats, 10 Hz and under 3 m accuracy. Indoors it may never get a fix, and that's normal.

5

## Heel sensor

Done

You need: the BNO085, five short wires, foam tape.

Board with the heel sensor outline and its five pads highlighted on the right

The BNO085 has lots of labelled pins. You only use five: VIN GND SDA SCL INT. Leave the rest empty.

1. Solder the five wires to the BNO085 first, on the side opposite its chip.
2. Stick it inside the outline on the board with foam tape, square to the outline. Heel is measured from it, so it mustn't wobble.
3. Solder the wires to the IMU pads.

{{IMU}}

1. Press R. It should say IMU: found.
2. Put the board flat on the table and type z Enter. Heel and pitch now read about 0.
3. Tip the board the way the boat heels to starboard. Heel should go positive.
  - If tipping sideways changes pitch instead, type a, lay it flat, and z again.
  - If heel goes negative, type f.

Check: flat reads 0, tipped to starboard reads plus, tipped nose-up gives plus pitch. The puck remembers these settings.

6

## Battery and charger

Done

You need: the TP4056 charger, the JST-PH socket, the battery, six short wires, the multimeter. Unplug the USB cable before starting this step.

Board with the power pad rows highlighted at the bottom: TP4056 row and the Qi, battery and XIAO battery row

Underside of the board showing where the TP4056 module sits and the same pads

1. Battery socket. Solder the JST-PH socket into the two holes marked BATT, from underneath (the battery is below the board). The square pad is +.
2. Check the battery. Meter on DC volts, probes into the back of the battery's plug. The pin that reads + (about 3.7–4.2 V with red probe on it) must line up with the square pad when plugged in. If it's backwards, don't plug it in: swap the wires in the plug or get a different battery.
3. Charger. Stick the TP4056 underneath, in its outline, USB end to the board edge. Wire its six pads to the six pads with the same names.
4. XIAO battery wires. The red wire from step 2 goes to BAT+ and the black to BAT− in the bottom row.

{{POWER}}

Before plugging the battery in, three meter checks (continuity / beep setting, battery unplugged):

- 3V3 pad to GND pad: no beep
- OUT+ to OUT−: no beep
- IN− to OUT−: no beep. They're kept apart on purpose: the charger's protection sits between them.

Any beep means a solder bridge somewhere. Find it before going on.

1. Plug in the battery. The board's LED should start blinking by itself: it's running on battery.
2. Plug the USB cable back in and open the monitor.

Check: the status line shows batt 3.9x V nn%, within about 0.05 V of what the meter reads across the battery.

7

## Wireless charging

Done

You need: the Qi receiver and coil, the Qi pad.

{{QI}}

1. Wire the Qi receiver's + / 5V to Qi 5V and its − / GND to Qi GND.
2. Unplug the USB (don't charge from both at once).
3. Lay the coil flat and centred on the Qi pad.

Check: the TP4056's red LED lights (charging). With the USB back in, the monitor says on the pad, charging. Lift the coil off and it says off the pad. When full, the TP4056 LED goes blue or green.

If the pad doesn't start: centre the coil and try again. Some pads are fussy with small coils, so try another pad if you have one.

8

## First track

Done

1. In the monitor type p1 Enter (this is puck 1), then r Enter to start recording.
2. Unplug the USB. The LED double-blinks while it records.
3. Put it in a food box with the GPS facing up, and go for a walk, a bike ride, or better, a sail. It records whenever it has a fix, up to about 3 hours.
4. Back home, plug in and close the Serial Monitor (only one program can talk to it at once).
5. In VS Code open a terminal (Terminal → New Terminal) in the wakeback folder and run:

pip install pyserial
python tools/pull_track.py

Check: it saves a file like puck1_103000.csv. Open wakeback/viewer/index.html in a browser and drag the file onto the map. That's your first real track.

## If something's wrong

You see | Try
Build or upload error in VS Code | Copy the red error text and send it to me. The test program hasn't been built on a real machine yet, so a small fix may be needed.
Upload fails, "no serial port" | Use a data USB cable (some are charge-only). Hold B while plugging in, then upload.
Nothing in the Serial Monitor | Press the XIAO's R button. Check the monitor speed is 115200.
GPS: NOT FOUND | Check the 3V3 and GND wires. Swap the TX and RX wires (the most common mistake).
GPS found but never gets a fix | Go outside with a clear sky. The first fix can take a few minutes.
IMU: NOT FOUND | Check VIN and GND. SDA and SCL may be swapped.
Heel reads wrong way or on the wrong axis | f flips it, a swaps heel and pitch, z zeroes it.
no battery | Check the battery's plugged in and charged, and the OUT+ and OUT− wires.
Always off the pad on the Qi pad | Centre the coil. Check the Qi 5V and GND wires. Try another pad.
Something gets hot | Unplug the battery straight away. Check the battery polarity and look for solder bridges.

## Which file is which

File | What it's for
wakeback-carrier-v1-gerbers.zip | Upload to JLCPCB as it is. That's all they need for bare boards.
wakeback-carrier-v1-BOM.csv | Only if JLCPCB fits the parts: the parts list, uploaded as the BOM.
wakeback-carrier-v1-CPL.csv | Only if JLCPCB fits the parts: where each part goes, uploaded as the CPL.
wakeback.zip | The whole project. Unzip it on your computer.
firmware/bench_test | The test program for the puck. Open this folder in VS Code (PlatformIO).
tools/pull_track.py | Copies a recorded track off the puck.
viewer/index.html | The replay viewer. Open it in a browser and drag tracks onto it.
server/ | The dock software. For the Raspberry Pi later; runs on your computer for testing.
hardware/carrier | The board design: pictures, notes, and the program that makes the Gerbers. You don't need to touch it.
BUILD.md | The breadboard version of these steps, if you'd rather try it before the boards arrive.

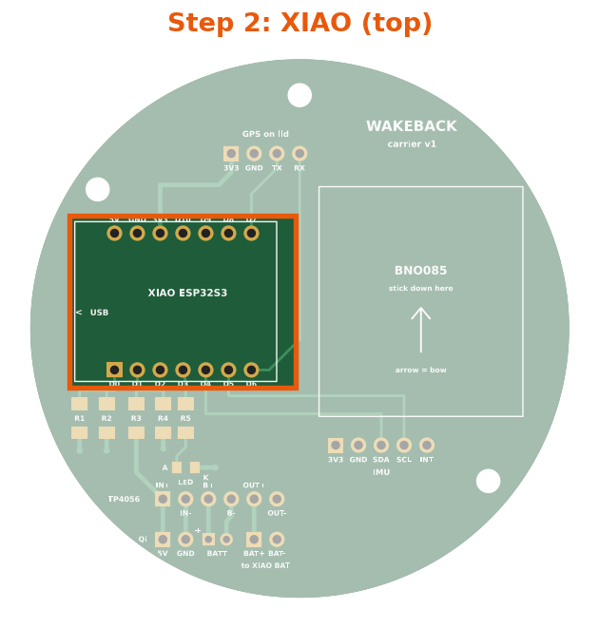
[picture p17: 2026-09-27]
hardware/carrier/out/step-xiao.png

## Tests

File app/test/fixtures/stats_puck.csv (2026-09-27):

t_ms | lat | lon | sog_kn | hdg | heel | pitch
1789900200000 | 53.650300 | -3.010200 | 0.00 | 0.0 | 12.0 | 1.0
1789900200100 | 53.650300 | -3.010200 | 0.01 | 0.2 | 12.0 | 1.0
1789900200200 | 53.650300 | -3.010200 | 0.01 | 0.3 | 12.0 | 1.0
1789900200300 | 53.650300 | -3.010200 | 0.02 | 0.5 | 12.0 | 1.0
1789900200400 | 53.650300 | -3.010200 | 0.03 | 0.7 | 12.0 | 1.0
1789900200500 | 53.650300 | -3.010200 | 0.03 | 0.8 | 12.0 | 1.0
1789900200600 | 53.650300 | -3.010200 | 0.04 | 1.0 | 12.0 | 1.0
1789900200700 | 53.650300 | -3.010200 | 0.05 | 1.2 | 12.0 | 1.0
1789900200800 | 53.650300 | -3.010200 | 0.05 | 1.3 | 12.0 | 1.0
1789900200900 | 53.650300 | -3.010200 | 0.06 | 1.5 | 12.0 | 1.0
1789900201000 | 53.650300 | -3.010200 | 0.07 | 1.7 | 12.0 | 1.0
1789900201100 | 53.650300 | -3.010200 | 0.07 | 1.8 | 12.0 | 1.0
1789900201200 | 53.650300 | -3.010200 | 0.08 | 2.0 | 12.0 | 1.0
1789900201300 | 53.650300 | -3.010200 | 0.09 | 2.2 | 12.0 | 1.0
1789900201400 | 53.650300 | -3.010200 | 0.09 | 2.3 | 12.0 | 1.0
1789900201500 | 53.650300 | -3.010200 | 0.10 | 2.5 | 12.0 | 1.0
1789900201600 | 53.650300 | -3.010200 | 0.11 | 2.7 | 12.0 | 1.0
1789900201700 | 53.650300 | -3.010200 | 0.11 | 2.8 | 12.0 | 1.0
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

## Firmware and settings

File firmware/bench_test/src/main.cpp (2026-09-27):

// WakeBack bench test
// ---------------------
// Checks each part of a breadboard puck and records a test track in the same CSV the viewer reads.
// Open a serial monitor at 115200 and type h for the commands.
//
// Wiring (XIAO ESP32S3), see BUILD.md:
//   GPS  (BE-880)   VCC 3V3, GND, GPS TX -> D7 (GPIO44), GPS RX -> D6 (GPIO43)
//   IMU  (BNO085)   VIN 3V3, GND, SDA -> D4 (GPIO5), SCL -> D5 (GPIO6)
//   LED             D3 (GPIO4) -> 330R -> LED -> GND
//   Battery sense   TP4056 OUT+ -> 100k -> A0 (GPIO1) -> 100k -> GND
//   Pad sense       Qi 5V       -> 100k -> A1 (GPIO2) -> 100k -> GND

#include <Arduino.h>
#include <Wire.h>
#include <LittleFS.h>
#include <Preferences.h>
#include <SparkFun_u-blox_GNSS_v3.h>
#include <Adafruit_BNO08x.h>

// ---------- pins ----------
static const int PIN_GPS_RX = 44;   // D7: data from the GPS
static const int PIN_GPS_TX = 43;   // D6: data to the GPS
static const int PIN_SDA = 5;       // D4
static const int PIN_SCL = 6;       // D5
static const int PIN_LED = 4;       // D3
static const int PIN_BATT = 1;      // A0, through a 100k/100k divider
static const int PIN_PAD = 2;       // A1, through a 100k/100k divider from the Qi receiver's 5 V

static const char *TRACK = "/track.csv";

SFE_UBLOX_GNSS_SERIAL gnss;
Adafruit_BNO08x bno(-1);
Preferences prefs;

bool gpsOk = false, imuOk = false, fsOk = false;
uint32_t gpsBaud = 0;

// latest readings
struct {
  uint8_t fix = 0, sats = 0;
  int32_t lat = 0, lon = 0;         // degrees * 1e7
  float sogKn = 0, cogDeg = 0, hAccM = 0;
  uint64_t tMs = 0;                 // UTC epoch ms, 0 until the GPS has the date and time
  uint32_t pvtThisSecond = 0;
  float rateHz = 0;
} gps;
float rollRaw = 0, pitchRaw = 0;    // from the IMU, degrees
float heel = 0, pitchDeg = 0;       // after zeroing and mounting corrections

// settings kept across power cycles
int puckNum = 1;
float zeroRoll = 0, zeroPitch = 0;
bool swapAxes = false, flipHeel = false;

// recording
bool recording = false, quiet = false;
File rec;
uint32_t recStarted = 0, lastFlush = 0, recLines = 0;

// ---------- helpers ----------
static int64_t daysFromCivil(int y, unsigned m, unsigned d) {   // Howard Hinnant's algorithm
  y -= m <= 2;
  const int64_t era = (y >= 0 ? y : y - 399) / 400;
  const unsigned yoe = (unsigned)(y - era * 400);
  const unsigned doy = (153 * (m + (m > 2 ? -3 : 9)) + 2) / 5 + d - 1;
  const unsigned doe = yoe * 365 + yoe / 4 - yoe / 100 + doy;
  return era * 146097 + (int64_t)doe - 719468;
}

static float readMilliVolts(int pin) {
  uint32_t sum = 0;
  for (int i = 0; i < 8; i++) sum += analogReadMilliVolts(pin);
  return sum / 8.0f * 2.0f;            // undo the 100k/100k divider
}

static int batteryPct(float mv) {      // resting single-cell LiPo, rough
  static const float V[] = {4200, 4100, 4000, 3900, 3800, 3750, 3700, 3650, 3600, 3500, 3300};
  static const int P[] = {100, 90, 78, 62, 45, 35, 22, 12, 6, 2, 0};
  if (mv >= V[0]) return 100;
  for (int i = 1; i < 11; i++)
    if (mv >= V[i]) return (int)(P[i] + (P[i - 1] - P[i]) * (mv - V[i]) / (V[i - 1] - V[i]));
  return 0;
}

static void savePrefs() {
  prefs.putInt("puck", puckNum);
  prefs.putFloat("zr", zeroRoll);
  prefs.putFloat("zp", zeroPitch);
  prefs.putBool("swap", swapAxes);
  prefs.putBool("flip", flipHeel);
}

// ---------- GPS ----------
static bool startGps() {
  static const uint32_t bauds[] = {38400, 115200, 9600, 57600, 230400};   // BE-880 usually ships at 38400
  Serial1.setRxBufferSize(4096);
  for (uint32_t b : bauds) {
    Serial1.begin(b, SERIAL_8N1, PIN_GPS_RX, PIN_GPS_TX);
    delay(50);
    if (gnss.begin(Serial1, 1200)) { gpsBaud = b; break; }
    Serial1.end();
  }
  if (!gpsBaud) return false;
  gnss.setUART1Output(COM_TYPE_UBX);        // binary only: NMEA text would crowd the link at 10 Hz
  gnss.setDynamicModel(DYN_MODEL_SEA);      // tuned for boats
  gnss.setNavigationFrequency(10);
  gnss.setAutoPVT(true);
  return true;
}

static void pollGps() {
  if (!gpsOk || !gnss.getPVT()) return;
  gps.fix = gnss.getFixType();
  gps.sats = gnss.getSIV();
  gps.lat = gnss.getLatitude();
  gps.lon = gnss.getLongitude();
  gps.sogKn = gnss.getGroundSpeed() / 1000.0f * 1.943844f;   // mm/s -> knots
  gps.cogDeg = gnss.getHeading() / 1e5f;
  gps.hAccM = gnss.getHorizontalAccEst() / 1000.0f;
  if (gnss.getDateValid() && gnss.getTimeValid()) {
    const int64_t days = daysFromCivil(gnss.getYear(), gnss.getMonth(), gnss.getDay());
    gps.tMs = (uint64_t)((days * 86400 + gnss.getHour() * 3600 + gnss.getMinute() * 60 + gnss.getSecond()) * 1000LL + gnss.getMillisecond());
  }
  gps.pvtThisSecond++;

  if (recording && gps.fix >= 2 && gps.tMs) {
    char line[112];
    const int n = snprintf(line, sizeof line, "%llu,%.7f,%.7f,%.2f,%.0f,%.1f,%.1f\n",
                           (unsigned long long)gps.tMs, gps.lat / 1e7, gps.lon / 1e7, gps.sogKn, gps.cogDeg, heel, pitchDeg);
    if (rec.write((const uint8_t *)line, n) != (size_t)n) {
      Serial.println("\n!! Flash full, recording stopped.");
      rec.close(); recording = false;
    } else recLines++;
  }
}

// ---------- IMU ----------
static bool startImu() {
  Wire.begin(PIN_SDA, PIN_SCL);
  Wire.setClock(100000);                    // the BNO08x stretches the clock; 100 kHz is the safe choice on ESP32
  if (!bno.begin_I2C(BNO08x_I2CADDR_DEFAULT, &Wire)) return false;
  // game rotation vector: gyro + accelerometer only, so metal on the boat can't upset heel and pitch
  return bno.enableReport(SH2_GAME_ROTATION_VECTOR, 20000);   // 50 Hz
}

static void pollImu() {
  if (!imuOk) return;
  if (bno.wasReset()) bno.enableReport(SH2_GAME_ROTATION_VECTOR, 20000);
  sh2_SensorValue_t v;
  while (bno.getSensorEvent(&v)) {
    if (v.sensorId != SH2_GAME_ROTATION_VECTOR) continue;
    const float w = v.un.gameRotationVector.real, x = v.un.gameRotationVector.i,
                y = v.un.gameRotationVector.j, z = v.un.gameRotationVector.k;
    rollRaw = atan2f(2 * (w * x + y * z), 1 - 2 * (x * x + y * y)) * RAD_TO_DEG;
    float s = 2 * (w * y - z * x);
    s = s > 1 ? 1 : s < -1 ? -1 : s;
    pitchRaw = asinf(s) * RAD_TO_DEG;
  }
  const float r = (swapAxes ? pitchRaw : rollRaw) - zeroRoll;
  const float p = (swapAxes ? rollRaw : pitchRaw) - zeroPitch;
  heel = flipHeel ? -r : r;
  pitchDeg = p;
}

// ---------- recording ----------
static void startRecording() {
  if (!fsOk) { Serial.println("Flash storage isn't working, can't record."); return; }
  if (recording) { Serial.println("Already recording."); return; }
  LittleFS.remove(TRACK);
  rec = LittleFS.open(TRACK, FILE_WRITE);
  if (!rec) { Serial.println("Couldn't create the track file."); return; }
  rec.print("t_ms,lat,lon,sog_kn,hdg,heel,pitch\n");
  recording = true; recStarted = millis(); recLines = 0;
  Serial.println(gps.fix >= 2 ? "Recording. Type r again to stop." : "Recording will start writing as soon as the GPS has a fix. Type r to stop.");
}

static void stopRecording() {
  if (!recording) return;
  rec.close(); recording = false;
  Serial.printf("Stopped. %lu points (%.1f minutes at 10 Hz). Type d to download it.\n", (unsigned long)recLines, recLines / 600.0f);
}

static void dumpTrack() {
  if (recording) stopRecording();
  File f = LittleFS.open(TRACK, FILE_READ);
  if (!f) { Serial.println("No track recorded yet. Type r to record one."); return; }
  char name[40] = "puck";
  // name it like a real puck file: puck<N>_<HHMMSS of the first point>.csv
  f.readStringUntil('\n');
  String first = f.readStringUntil('\n');
  uint64_t t0 = strtoull(first.c_str(), nullptr, 10);
  const uint32_t secOfDay = (uint32_t)((t0 / 1000) % 86400);
  snprintf(name, sizeof name, "puck%d_%02lu%02lu%02lu.csv", puckNum, (unsigned long)(secOfDay / 3600), (unsigned long)(secOfDay / 60 % 60), (unsigned long)(secOfDay % 60));
  f.seek(0);
  const bool wasQuiet = quiet; quiet = true;
  Serial.printf("\n---BEGIN %s---\n", name);
  uint8_t buf[512];
  size_t n;
  while ((n = f.read(buf, sizeof buf)) > 0) { Serial.write(buf, n); delay(1); }
  Serial.println("---END---");
  f.close();
  quiet = wasQuiet;
}

// ---------- status ----------
static void printStatus() {
  const float batt = readMilliVolts(PIN_BATT), pad = readMilliVolts(PIN_PAD);
  const bool onPad = pad > 4000;
  const char *chg = !onPad ? "off the pad" : batt >= 4150 ? "on the pad, full" : "on the pad, charging";
  const char *fixTxt[] = {"no fix", "dead reckoning", "2D fix", "3D fix", "GNSS+DR", "time only"};
  Serial.printf("GPS %s", gpsOk ? (gps.fix < 6 ? fixTxt[gps.fix] : "?") : "NOT FOUND");
  if (gpsOk) Serial.printf(", %u sats, %.0f Hz, +/-%.1f m | %.2f kn %03.0f deg", gps.sats, gps.rateHz, gps.hAccM, gps.sogKn, gps.cogDeg);
  if (imuOk) Serial.printf(" | heel %+5.1f pitch %+5.1f", heel, pitchDeg);
  else Serial.print(" | IMU NOT FOUND");
  if (batt > 2500) Serial.printf(" | batt %.2f V %d%%", batt / 1000, batteryPct(batt));
  else Serial.print(" | no battery");
  Serial.printf(" | %s", chg);
  if (recording) Serial.printf(" | REC %lus %lu pts", (unsigned long)((millis() - recStarted) / 1000), (unsigned long)recLines);
  Serial.println();
}

static void help() {
  Serial.printf(
    "\nWakeBack bench test, puck %d\n"
    "  h      this help\n"
    "  s      one status line now\n"
    "  q      pause/resume the status lines\n"
    "  r      start/stop recording a track\n"
    "  d      download the recorded track (copy it with tools/pull_track.py)\n"
    "  e      erase the recorded track\n"
    "  z      zero heel and pitch (sit the puck level first)\n"
    "  f      flip heel sign (heel should be + when tipped to starboard)\n"
    "  a      swap the heel and pitch axes (if tipping sideways shows as pitch)\n"
    "  p<N>   set the puck number, e.g. p3\n"
    "  i      what was found at start-up\n\n", puckNum);
}

static void report() {
  Serial.printf("GPS:     %s", gpsOk ? "found" : "NOT FOUND. Check VCC/GND, and that GPS TX goes to D7 and GPS RX to D6.\n");
  if (gpsOk) Serial.printf(" at %lu baud, set to 10 Hz, sea mode\n", (unsigned long)gpsBaud);
  Serial.printf("IMU:     %s\n", imuOk ? "found (BNO085, game rotation vector at 50 Hz)" : "NOT FOUND. Check VIN/GND, SDA to D4, SCL to D5.");
  Serial.printf("Storage: %s", fsOk ? "ok, " : "NOT WORKING\n");
  if (fsOk) Serial.printf("%.1f MB free\n", (LittleFS.totalBytes() - LittleFS.usedBytes()) / 1048576.0);
  Serial.printf("Settings: puck %d, zero roll %.1f pitch %.1f, axes %s, heel %s\n", puckNum, zeroRoll, zeroPitch, swapAxes ? "swapped" : "normal", flipHeel ? "flipped" : "normal");
}

static void command(String c) {
  c.trim();
  if (!c.length()) return;
  const char k = tolower(c[0]);
  switch (k) {
    case 'h': help(); break;
    case 's': printStatus(); break;
    case 'q': quiet = !quiet; Serial.println(quiet ? "Status lines paused (q to resume)." : "Status lines on."); break;
    case 'r': recording ? stopRecording() : startRecording(); break;
    case 'd': dumpTrack(); break;
    case 'e': if (recording) stopRecording(); LittleFS.remove(TRACK); Serial.println("Track erased."); break;
    case 'z': zeroRoll = swapAxes ? pitchRaw : rollRaw; zeroPitch = swapAxes ? rollRaw : pitchRaw; savePrefs(); Serial.println("Zeroed. Heel and pitch now read 0 in this position."); break;
    case 'f': flipHeel = !flipHeel; savePrefs(); Serial.println(flipHeel ? "Heel sign flipped." : "Heel sign normal."); break;
    case 'a': swapAxes = !swapAxes; zeroRoll = zeroPitch = 0; savePrefs(); Serial.println("Axes swapped. Sit it level and type z."); break;
    case 'p': { int n = c.substring(1).toInt(); if (n >= 1 && n <= 99) { puckNum = n; savePrefs(); Serial.printf("This is now puck %d.\n", n); } else Serial.println("Use p then a number, e.g. p3"); } break;
    case 'i': report(); break;
    default: Serial.println("Unknown command. Type h for help.");
  }
}

// ---------- LED: slow blink = no fix, steady blink = fix, double blink = recording ----------
static void led() {
  const uint32_t m = millis();
  bool on;
  if (recording) { const uint32_t p = m % 1000; on = p < 80 || (p > 200 && p < 280); }
  else if (gps.fix >= 3) on = m % 1000 < 100;
  else on = m % 2000 < 60;
  digitalWrite(PIN_LED, on);
}

void setup() {
  pinMode(PIN_LED, OUTPUT);
  digitalWrite(PIN_LED, HIGH);
  analogReadResolution(12);
  Serial.begin(115200);
  const uint32_t t = millis();
  while (!Serial && millis() - t < 3000) delay(10);   // wait briefly for the USB serial monitor

  prefs.begin("puck", false);
  puckNum = prefs.getInt("puck", 1);
  zeroRoll = prefs.getFloat("zr", 0); zeroPitch = prefs.getFloat("zp", 0);
  swapAxes = prefs.getBool("swap", false); flipHeel = prefs.getBool("flip", false);

  Serial.println("\nWakeBack bench test starting…");
  fsOk = LittleFS.begin(true);
  gpsOk = startGps();
  imuOk = startImu();
  digitalWrite(PIN_LED, LOW);
  report();
  help();
}

void loop() {
  static String in;
  static uint32_t lastStatus = 0, lastRate = 0;
  while (Serial.available()) {
    const char ch = Serial.read();
    if (ch == '\n' || ch == '\r') { command(in); in = ""; }
    else if (in.length() < 32) in += ch;
  }
  pollGps();
  pollImu();
  const uint32_t m = millis();
  if (m - lastRate >= 1000) { gps.rateHz = gps.pvtThisSecond * 1000.0f / (m - lastRate); gps.pvtThisSecond = 0; lastRate = m; }
  if (recording && m - lastFlush >= 1000) { rec.flush(); lastFlush = m; }   // a flat battery or a swim loses a second, not the track
  if (!quiet && m - lastStatus >= 1000) { printStatus(); lastStatus = m; }
  led();
}

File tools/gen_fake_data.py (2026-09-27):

#!/usr/bin/env python3
"""Generate fake puck logs for demoing the WakeBack viewer.

Writes CSV files in the exact format the puck firmware will produce:
    t_ms,lat,lon,sog_kn,hdg,heel,pitch
plus one GPX file as if it came from a mate's phone.

Usage:  python tools/gen_fake_data.py            # writes into data/sessions/
        python tools/gen_fake_data.py --out /tmp/x
"""
import argparse, json, math, random, os
from datetime import datetime, timezone, timedelta

KN = 1.943844                      # m/s -> knots
CENTRE = (53.6503, -3.0102)        # Marine Lake, Southport (approximate)

def rad(d): return d * math.pi / 180

def sim_boat(base_kn, seed, start_offset, heel_up, wind=25, t0=None, laps=3):
    R = random.Random(seed)
    u = (math.sin(rad(wind)), math.cos(rad(wind)))       # upwind unit vector
    v = (math.cos(rad(wind)), -math.sin(rad(wind)))      # across-wind unit vector
    mk = lambda a, c: (u[0]*a + v[0]*c, u[1]*a + v[1]*c)
    marks = [mk(380, 10), mk(-360, 45), mk(-120, -45)]
    x, y = marks[2][0] + start_offset, marks[2][1] - 15
    side, tack_t, mi, lap, dside = 1, -99, 0, 0, 1
    dt, s, rows = 0.1, 0.0, []
    while s < 3*3600 and lap < laps:
        tx, ty = marks[mi][0]-x, marks[mi][1]-y
        d = math.hypot(tx, ty)
        if d < 12:
            mi = (mi+1) % 3
            if mi == 0: lap += 1
            continue
        want = (math.degrees(math.atan2(tx, ty)) + 360) % 360
        diff = ((want - wind + 540) % 360) - 180
        if abs(diff) < 42:                                   # beating
            lat_off = x*v[0] + y*v[1]
            if lat_off*side > 60: side, tack_t = -side, s
            hdg, k, heel, pitch = wind + side*42, 0.82, side*heel_up, -1   # port tack (TWA>0) heels to starboard (+)
        elif abs(diff) > 140:                               # run: sail by the lee-ish angles and gybe down the leg
            lat_off = x*v[0] + y*v[1] - (marks[mi][0]*v[0] + marks[mi][1]*v[1])
            if lat_off*dside > 35: dside, tack_t = -dside, s
            hdg, k, heel, pitch = wind + 180 - dside*22, 0.95, -dside*heel_up*0.25, 3
        else:
            hdg, k = want, 1.15
            sgn = 1 if diff > 0 else -1
            heel, pitch = sgn*heel_up*0.7, 0.5
        since = s - tack_t
        if since < 8:
            k *= 0.55 + 0.45*since/8
            heel *= since/8
        heel += 2.5*math.sin(s/3.1+seed) + 1.5*(R.random()-0.5)
        pitch += 1.2*math.sin(s/2.3+seed) + 0.8*(R.random()-0.5)
        kn = base_kn*k*(1 + 0.07*math.sin(s/9+seed) + 0.06*(R.random()-0.5))
        ms = kn/KN
        x += math.sin(rad(hdg))*ms*dt
        y += math.cos(rad(hdg))*ms*dt
        nx, ny = x + (R.random()-0.5)*1.2, y + (R.random()-0.5)*1.2
        lat = CENTRE[0] + ny/111320
        lon = CENTRE[1] + nx/(111320*math.cos(rad(CENTRE[0])))
        rows.append((t0 + timedelta(seconds=s), lat, lon, kn + 0.05*(R.random()-0.5), hdg % 360, heel, pitch))
        s += dt
    return rows

def drift(a, b, R, dt=0.1):
    """Rows for a boat drifting slowly from the last row of a to the first row of b (between races)."""
    t0, lat0, lon0 = a[-1][0], a[-1][1], a[-1][2]
    t1, lat1, lon1 = b[0][0], b[0][1], b[0][2]
    n = int((t1 - t0).total_seconds() / dt)
    rows, hdg = [], R.random() * 360
    for k in range(1, n):
        f = k / n
        hdg = (hdg + (R.random() - 0.5) * 4) % 360
        rows.append((t0 + timedelta(seconds=k*dt),
                     lat0 + (lat1-lat0)*f + (R.random()-0.5)*2e-5,
                     lon0 + (lon1-lon0)*f + (R.random()-0.5)*3e-5,
                     0.3 + 0.5*R.random(), hdg, (R.random()-0.5)*3, (R.random()-0.5)*2))
    return rows

def two_races(base_kn, seed, offset, heel, t0, gap_min=14):
    """Race 1 (3 laps), drift about for a bit, race 2 (2 laps, different seed). One log file, like a real morning."""
    r1 = sim_boat(base_kn, seed, offset, heel, t0=t0, laps=3)
    start2 = t0 + timedelta(minutes=57)          # one gun for the whole fleet
    assert start2 > r1[-1][0] + timedelta(minutes=5), 'race 1 ran too long for the gap'
    r2 = sim_boat(base_kn * 0.97, seed + 100, -offset, heel, t0=start2, laps=2)
    return r1 + drift(r1, r2, random.Random(seed)) + r2

def write_csv(path, rows):
    with open(path, 'w') as f:
        f.write('t_ms,lat,lon,sog_kn,hdg,heel,pitch\n')
        for t, lat, lon, sog, hdg, heel, pitch in rows:
            f.write(f'{int(t.timestamp()*1000)},{lat:.7f},{lon:.7f},{sog:.2f},{hdg:.0f},{heel:.1f},{pitch:.1f}\n')

def write_gpx(path, name, rows, every=10):
    with open(path, 'w') as f:
        f.write('<?xml version="1.0" encoding="UTF-8"?>\n<gpx version="1.1" creator="phone" xmlns="http://www.topografix.com/GPX/1/1">\n')
        f.write(f'<trk><name>{name}</name><trkseg>\n')
        for t, lat, lon, *_ in rows[::every]:            # phones log at 1 Hz
            f.write(f'<trkpt lat="{lat:.6f}" lon="{lon:.6f}"><time>{t.strftime("%Y-%m-%dT%H:%M:%SZ")}</time></trkpt>\n')
        f.write('</trkseg></trk>\n</gpx>\n')
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

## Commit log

2026-09-27 WakeBack: viewer, dock server, phone/tablet app, hardware, firmware bench test
    - app/: Android app that runs the dock API on the phone and hosts the real viewer
    - .github/workflows/build-apk.yml: builds and tests the app, publishes WakeBack.apk as a release
    - server/app.py: refuse '.'/'..' day and file names
    - viewer: hand full screen and GPX export to the app when running inside it
    Claude-Session: https://claude.ai/code/session_01EHncjVG7Vms8XRqiCuT31o
    [partitions.csv, puck1_103000.csv, puck1_174500.csv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]
2026-09-27 Weather: Get weather fills in wind direction, speed and gusts from Open-Meteo
    - Viewer: Get weather button next to Wind; hourly wind for where and when you
    sailed (forecast API, ERA5 archive for older days), saved with the day in
    meta.weather. Sets the wind per race, live speed/gusts on the map and the
    big screen, hourly strip in the panel. Estimate/typed wind still override.
    A day with weather now brings its own wind instead of the browser's last one.
    - app.py and the phone dock keep meta.weather (cleaned the same way); sync
    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
2026-09-27 Stage 1: venues and owner/sailor
    - Sessions are now a sailing date + venue (2026-09-20_southport-sc). The venue is
    found from the track's first position (data/venues.json); somewhere new gets
    'New venue near ...' until you name it. Old date-only folders are converted on start.
    - Every track records its owner (whose puck/phone sent it: the app's 'You' profile,
    the puck's owner, or WAKEBACK_OWNER for a club dock) separately from the sailor
    (crew). Owners' emails stay on the server; only names are listed.
    - API: /api/venues (list/add/rename), /api/sessions/<id>/move, upload owner fields,
    JSON errors for /api/*.
    - Viewer: sessions shown as date + venue with a venue filter; name a new v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
    [fake_puck_upload.py, gen_fake_data.py]
2026-09-27 Demo data in the date + venue layout; newer checkout/setup-java actions
    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
    [puck1_103000.csv, puck1_174500.csv, puck2_103000.csv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]
2026-09-27 Server as a container for the NAS: Dockerfile, docker-compose.yml, GHCR image build
    gunicorn (1 process, 8 threads) serves app.py + the viewer on port 5000; data in
    a volume. GitHub builds ghcr.io/jb65uk/wakeback-server:latest for amd64 and arm64.
    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
2026-09-27 Sign release APKs with one permanent key (from repo secrets)
    Every build so far used a throwaway debug key, so Android refused to install an
    update over an earlier build. app/tool/use_release_key.py switches the release
    build to android/key.properties; the workflow writes it from the
    ANDROID_KEYSTORE_BASE64 / ANDROID_KEYSTORE_PASSWORD secrets (warns and falls back
    to the debug key if they're not set yet).
    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
2026-09-27 Stage 2: accounts, friends, sharing, admin dashboard
    Server (WAKEBACK_ADMIN=<email> switches it on; a dock Pi/phone without it is unchanged):
    - server/accounts.py: sign up / log in (email + password, tokens), pending approval
    with an Auto-approve setting, friends (request/accept/decline), per-track sharing
    (friends/private) kept in owners.json, admin API, audit log. SQLite in data/.
    - /api/sessions lists only what the signed-in user may see (own, friends' shared,
    unowned club tracks; admin sees all) with owners/sharing/mine per file.
    - viewer/admin.html: users (approve, disable, rename, reset password, delete),
    auto-approve switch, every track (owner, sharing, remove), recent changes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
2026-09-27 Sessions tab with Stats and League; stats API on server and phone; ?session deep link; demo button follows demo mode
    - server/stats.py: per-track distance, time on the water, top speed (99.5th pct), average, smoothed
    like the viewer; cached per session in stats.json. /api/stats (yours) and /api/league (you + friends,
    private sails off the board even for the admin), stats in /api/sessions.
    - app/lib/dock/stats.dart: identical Dart port; pocket dock serves the same routes. Parity test with
    fixtures whose expected values come from running stats.py.
    - App opens on a native Sessions tab: list with Friends/Private switch per session (local + server),
    Stats sub-tab (totals, records, favouri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
    [stats_puck.csv]
2026-09-27 Roadmap: puck setup + key, firmware OTA from the dashboard, app update button, 2FA (to do, in that order)
    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
2026-09-27 Roadmap: GDPR / personal-data stage (delete + export my data, privacy note, emails stay on the server)
    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
2026-09-27 Case: lid-mount (lid with bayonet lugs) and a matching cradle for hanging the puck under a thwart; fit-checked, README
    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
    [wakeback-cradle-lid.stl, wakeback-lid-mount.stl]
2026-09-27 Roadmap: firmware self-calibration (orientation, mounting twist, level, mag, GPS warm start)
    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
2026-09-28 Personal bests, badges, offline maps, share card, wind vs speed
    - Stats (server + identical Dart port): max_heel, capsizes (heel > 80 deg for 10 s), and with the day's
    weather wind_kn / up_kn / down_kn / vmg_kn per track; summary adds wind-strength bins, upwind/downwind/VMG
    and heel bests; stats.json cache keyed by size + weather + version.
    - Sessions tab: 'New personal best' toast + card when a track beats your earlier ones (ever / this year);
    share button draws a 1080x1350 PNG of the day (tracks, numbers) for the share sheet.
    - Stats tab: 'The wind' section (upwind, downwind, best VMG, most heel, by wind strength) and 17 badges.
    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
2026-09-28 NAS: Watchtower keeps the server image current (label-scoped, every 30 min, cleans up old images)
    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
2026-09-28 Server: brute-force brake on login/status/sign-up (per email + per address, 10-min window); nightly backup container in compose
    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
2026-09-30 Record tab: record a sail with the phone's own GPS
    New Record tab (between Sessions and Replay): big live speed, heading, top speed,
    time, distance and average, and the track drawn as you go. Start / Pause / Resume /
    Finish; a finished sail goes into Sessions like a puck's (venue, owner, stats,
    bests, sync), saved as the puck CSV so heading reaches wind-vs-speed. Share GPX
    from the saved card.
    Keeps recording with the screen off (Android foreground service with a
    notification). Every fix is written to a draft straight away, so if the app is
    killed or the phone dies the recording comes back paused on next start.
    GPS filter (default ±30 m) in the Record tab.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
2026-09-30 Sessions: delete a session (with confirm) from the card's menu
    A ⋮ menu on each session card with Share a picture and Delete session. Delete asks
    first, removes the session from the phone, and removes your own tracks from the
    server too when signed in (a mate's track comes back with the next Sync: it's theirs).
    Claude-Session: https://claude.ai/code/session_01FASpnZvve7zfH4AEeTnZaJ
2026-09-30 Boats per session; delete a venue's offline map
    Boats: Setup → Your boats (the first is your usual boat; tap another to make it
    usual). Your usual boat goes on every track you record or that lands from your
    puck. Each session card shows the boat as a chip: tap to pick another, add a new
    one, or clear it. Stored on the track's owner entry (boat), sent with uploads
    and synced both ways; server accepts boat on /api/upload and track settings and
    returns boats in /api/sessions.
    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
2026-10-03 Your sails sync on their own, and stay yours on every device
    A sail recorded on the phone showed in the tablet's Stats (those come from the
    server) but not in Sessions or Replay, because tracks only moved when you opened
    Sync and tapped Sync all.
    - Signed in, the app now syncs by itself when it opens, when you come back to it,
    after a recording, and when you pull down on Sessions.
    - Tapping a record in Stats for a sail that isn't on this device fetches it first.
    - Your own sail that comes down from the server is filed as yours (sharing switch,
    boat, bests), not as a mate's; ones an older build filed wrongly are put right.
    - A sail deleted from the server on one device is no longer sent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
2026-10-03 Races suggested from the tracks; sail times on session cards
    Every fix already carries its time, so races can be worked out without logging
    anything extra.
    - Replay: a session with no races yet shows the likely ones under Races (boats
    milling about, then setting off together, then stopping), each with how sure it
    is. Tick and Add selected; nothing is added until you say. Suggest races (was
    Auto split) looks again and skips races you already have.
    - With one track it is only ever offered as a maybe.
    - Sessions: each card shows when you sailed (10:30-12:16), one span per sail when
    there was a break ashore, so two sails in a day read as two.
    - The suggestion rules are checked against m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
2026-10-03 Race times: the name and Delete fit the panel
    On the tablet the race row was wider than the panel, so the name was cut off and
    Delete needed a sideways scroll. Delete now sits beside the name, the two times
    share the row below, and the panel no longer scrolls sideways.
    Claude-Session: https://claude.ai/code/session_01XACNjMNyMr9MkgQPredoAN
2026-10-04 Tiny tracks don't count; stats by boat; forgot password; export and delete account; screen-size pass
    Tiny tracks
    - A track under 5 minutes moving or 0.2 nm is still saved and replayable but is
    left out of stats, bests, badges and the league (server and app alike).
    - Finishing a recording that short says so and offers Discard / Save anyway /
    Keep recording.
    Stats by boat
    - Stats has a boat picker once you've sailed more than one boat.
    - The League can be narrowed to a class (Solo, Mirror...: the boat's name
    without its sail number), so like races like.
    Forgot password (no email service, so it goes through the admin)
    - Log in > Forgot your password? asks for a reset. The request shows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
    [test_server.py]
2026-10-04 Stats parity test: count its short fixtures; the tiny-track limits are settable for tests
    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
2026-10-10 Case: add printed TPU gasket as an alternative to the 70 x 2 O-ring
    Fits the existing groove; base and lid geometry unchanged. Regenerated STLs and previews.
    Claude-Session: https://claude.ai/code/session_01GJgQx5WNGNpzviHDiQHMv1
    [wakeback-base.stl, wakeback-gasket-tpu.stl, wakeback-lid-mount.stl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]
2026-10-20 Puck mk1: waterproof push button in the side wall (case + bench firmware)
    Case: 12 mm hole on a flat boss in the stern-starboard wall for a 12 mm anti-vandal
    momentary button (ring LED optional); base 4 mm taller so the button body sits above the
    board; switch modelled as an inside part so the fit checks cover it; new case-switch.png.
    Firmware: D2 button (tap = record on/off, hold 2 s = sleep, press = wake, knock-proof),
    D9 ring LED (copies status, breathes charging / solid full on the pad), 30 min auto-off (o),
    x = sleep now. Docs: BUILD.md stage 4b, carrier and case READMEs, roadmap. export_glb fixed.
    Claude-Session: https://claude.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
2026-10-21 Case: shorter lid thread (6 mm) so the push button only costs 2 mm of height, not 4
    Claude-Session: https://claude.ai/code/session_01S1yNAv1GggrVU8YHAVtrvC
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2026-10-24 Puck: free-space figure cached (LittleFS walk stalled the page and WiFi); radio awake in setup mode
    Claude-Session: https://claude.ai/code/session_01RsVJtpqcEZYwYYfKA2kaND
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2026-10-24 Puck: twist only learnt after 15 s under way with a clean fix (bench GPS jitter was teaching it rubbish)
    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
2026-10-25 Puck: don't crash when switching from the setup WiFi to the hotspot
    Setup AP -> WIFI_OFF -> STA in one go left the driver still stopping ("netstack cb reg failed with
    12308"), so the station came up with no network stack and the first packet after "Joined James Phone"
    jumped to address 0 (InstrFetchProhibited), reboot, setup WiFi again: a loop, seen the first time a
    puck went setup -> phone hotspot for real (25 Oct). Now the radio is waited off (and settles 600 ms)
    before any mode change, in both directions.
    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
2026-10-25 Puck: WiFiClient before HTTPClient, so the client outlives the request (crash on every hello)
    The decoded trace put the InstrFetchProhibited at the end of hello(): HTTPClient's destructor closing a
    WiFiClient that had already been destroyed (declared after it, so destroyed before it). Same order in
    checkin() and the firmware check.
    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
2026-10-25 Set up a puck: "Continue without a key" when the server's unreachable; puck: auto-record ignores GPS jitter
    App: if the key request fails (no signal, server down) the error card now offers Continue without a key
    as well as Try again; the puck still uploads to the phone and Set up again gives it a key later.
    Puck: auto-record only starts when the boat is both far enough from rest to beat the fix accuracy
    (max of 30 m and 4x hAcc) and has held a speed above 0.5 kn for 5 s. Indoor GPS wander on the bench
    was starting recordings on its own, which also kept the puck off the dock. The serial `u` says so
    when a recording is what's stopping it.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
2026-10-25 Puck firmware: robustness fixes
    OTA probation really runs (verifyRollbackLater), old bench calibration keys cleared once
    on first boot (wbv schema key), the wake-up press is ignored until the button is seen
    released, sleeping on the pad doesn't arm the pad wake (it would wake at once), the
    auto-off clock and manual recordings follow the held-speed rule, serial never blocks a
    host that isn't reading, free-space measured every 10 s not every flush, the button and
    LED keep working mid-upload, dock firmware only installs a newer release (never on a
    local 1.0.0/dev build), no setup AP when the pad join fails (retry every 2 min instead),
    an explicit cfg flag says whether the puck has been set up,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
2026-10-25 Server: lock down the session routes, puck keys and dock settings
    Only real tracks (.csv/.gpx) are served or deleted; the JSON sidecars and made-up
    names are 404. Meta, races and crew need a session that exists and a track in it
    you can see (read) or own (write), so nothing can be written under an arbitrary
    folder name any more. Moving a session needs every owner's say-so, and a renamed
    file keeps its owner and sailor. Naming a new venue is for anyone; changing a
    named one is the admin's. The puck list and the sailor picker only show what the
    viewer could open. A puck key only counts for the puck it was issued to. Sign-up,
    friends, passwords and puck keys are 404 when accounts are off. Admin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
2026-10-25 Puck firmware: simpler settings and setup page
    The rate setting is gone (5 Hz moving, 1 Hz still, always), twist is always learnt, the
    pitch flip is gone. The page keeps battery, tracks, record, WiFi settings, Boat is level,
    Mounted on deck / under the thwart and firmware update in the open; GPS detail, compass,
    twist and level offsets are under Advanced. Replies show in a toast, HTTP errors are
    shown as text, the form fills again once you leave a field, Done says setup finished
    rather than Lost the puck, small files show in KB, GPS reads Searching / Ready, and
    the storage text says about 4.5 hours.
    Claude-Session: https://claude.ai/c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
2026-10-25 App: You tab, puck setup and Sync made plainer
    - You → Advanced: the fleet counter, port line and phone-address rows are gone; the hotspot is
    read-only ("set by Set up a puck"); one server editor; a status line only when the dock's port
    couldn't be opened ("Another app is using the dock's port. Restart WakeBack.")
    - Rows on the Dock page come from the pucks set up on this phone (the highest number)
    - Set up a puck: a key issued for this number is reused on Try again rather than issued again;
    renumbering a puck revokes the old number's key; the finish screen shows the hotspot name and
    password with Copy buttons and points at You → Pucks → See them check in; a Log in button when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
2026-10-25 Viewer: dock page on a real server, admin fixes, replay cleanups, /record route
    Dock page: no PIN field, no NAS row, the fake_pucks hint only in demo mode,
    polls every 10 s, neutral wording when the server can't be reached. Admin:
    Make/Remove admin in the user menu, every audit action labelled, the delete
    confirm says what happens (tracks stay as club tracks), the Tracks tab picks
    the owner from the server's owner_emails instead of guessing by name, section
    comments straightened out. Replay: dead CSS and state gone (appmode, .tkrow,
    selMark, dock.me, dockon), the tackLegend selector no longer restyles the
    friends switch, parseTime's duplicate branches collapsed, fetchTracks and
    refreshSessio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
2026-10-25 Tools: one upload() shared by the fake pucks, --key everywhere, no crash on a refused upload
    fake_pucks.py and pull_track.py import upload() from fake_puck_upload.py instead
    of each carrying its own multipart form. All three take --key (sent as
    X-Puck-Key) for a server with accounts on. A refused upload or check-in prints
    the server's reply and the loop carries on. gen_fake_data's comment names the
    button as it is now ("Suggest races").
    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
2026-10-25 Guide in the app (0.16.0)
    You → Help → Guide: starting out, setting up a puck, the button and the light, a sailing day, recording
    with the phone, sails/stats/friends, maps with no signal, and what to do when it's not working. Plain
    words, no internals. The puck and setup screens open it at the right section; the welcome screen has
    "How it works". The button/LED table matches firmware/puck/README.md.
    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
2026-10-25 App: talk to the puck over Bluetooth — setup, status, buttons and firmware updates (0.17.0)
    Setting up a puck no longer needs its WiFi or the 6-second button hold: with the puck awake (on the pad, or
    press its button) the app finds "WakeBack puck N" over Bluetooth, reads it, sends the hotspot details and
    your key, and tells it to go and find the hotspot. "Find pucks nearby" (on the setup screen and under Your
    pucks) lists every puck it can hear with its signal, so a new one can be set up from the list. The old
    setup-WiFi route stays as the fallback, and the app drops to it by itself if no puck is heard.
    The puck screen connects over Bluetooth when it opens and shows battery, charging, rec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
2026-10-26 Puck screen: calibration readout + Advanced (twist, heel flip, reset), sail-over and sleep timings as settings, auto-off switch, delete/erase tracks on the puck
    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
2026-11-10 App 0.19.0: Bluetooth link lock, live puck screen, resumable track pulls, tablet layout; puck reports real battery use
    App: PuckLink replaces the busy flag; commands queue per connection; puck screen refreshes
    every 2 s and folds its settings away; partial tracks carry on after a dropped link; banner
    and toast when tracks come over in the background; Your pucks card rebuilds itself;
    navigation rail and a centred content column on wide screens; tests for .wbt, CRC, the lock.
    Firmware: since_full_s in status, status polls no longer logged.
    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
2026-11-10 After review: don't wake a resting GPS on the way to sleep, re-configure and watch the GPS after a rest, fail fast on a dropped link
    Firmware: goToSleep leaves a GPS that's already in standby alone (the command itself would wake it);
    gpsWake says the whole configuration again; ten seconds of GPS silence sets it up again; IMU reports
    re-asked after 5 s of silence; "full" latched for the pad visit so since_full_s survives the cell
    settling; a long Bluetooth command no longer trips the rest watchdog.
    App: a waiting command fails the moment the link drops; a scan always ends; setState guard.
    Claude-Session: https://claude.ai/code/session_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
